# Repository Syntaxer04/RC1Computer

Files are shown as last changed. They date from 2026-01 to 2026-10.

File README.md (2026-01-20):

# RC1Computer
8-Bit Relay Computer inspired by Harry Porter and DipDot
# General Information
This Computer, inspired Harry H Porter III, Ph.D, Paul Law, and Youtuber DipDot, is (almost) completly made out of relays, 607 of them to be exact.

# Specifications
- 32 kb RAM
- It has ~11~ 15 8 Bit Registers. Some of them can also funtcion as 16 Bit Registers.
- A clock rate Between 3 and 8 Hertz
- 8 Bit Data and Instruction Bus, as well as an 16* Bit Adress Bus
<sub>*only 15 bits are actually used, but the 16th Bit is still usable for other Peripherals/More Memeory</sub>

# Changes in V0.2
- Changed how I managed the Bus on the RC-1. The Bus Board now encompasses all Register Signals and otherwise, except for the Timing pulses, which is only used by the Controller.
- Caught most the Routing mistakes I made in the first Version. The second run really helped spotting obvious and not so obvious mistakes.
- Added a board for the front panel functions. The switches are not mounted on the Board however, and so are the LEDs.
- I also started experimenting with Capacitor Storage. I included my initial design in this version.
- The memory board had an overhaul, with more isolation and better logic.
- The ALU has been split into two boards. I was able to do this because of the new backplane.

# Future features
- ~I want to make some sort Storage medium. A Tape interface, similar to DipDot's design, would be nice, although for a computer like that kind of lame in my opinion. I am thinking more like a paper based interface, like the one Usagi electric build for the [UE1](https://www.youtube.com/playlist?list=PLnw98JPyObn0v-98gRV9PfzAQONTKxql3). One Slight Problem thogh: _Reading_ may be somewhat easy, the _writing_ on the other hand may be a little challenge... We'll burn that bridge when we get there.~
- Tape Loader has been added, function not Tested however.
- The Second thing i want to make for this project is some sort of Serial/ Terminal output. That itself is not that hard all things considered, it's nearly a chip solution. The real problem is that the Computer most likely lacks any sort of speed for that kind of outpu. So i either have to buffer the output, make it _exceptionaly_ slow, or find some other way of sending a serial signal of of the Computer.

# Links
[Paul Law´s Youtube channel](https://www.youtube.com/@paul80nd), and his [personal Blog](https://www.relaycomputer.co.uk/).
[Harry Porter´s Webiste](https://web.cecs.pdx.edu/~harry/Relay/index.html), specifically, [this PDF](https://web.cecs.pdx.edu/~harry/Relay/RelayPaper.pdf).
Lastly, [DipDot´s Youtube channel](https://www.youtube.com/@dipdoting). He was the main inspiration for this project and his videos are well made.

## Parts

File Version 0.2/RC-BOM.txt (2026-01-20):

Bill of Materials

ALU-LOGIC: 	 52 1N914  
	  	 45 LEDs
		 52 HK19F-DC5V Relays
		 45 330 Ohm Resistors

ALU-FULLADDER:	 62 1N914  
	  	 21 LEDs
		 63 HK19F-DC5V Relays
		 21 330 Ohm Resistors

CONTROLLER:	 60 1N914  
	  	 2 2*12 connector
		 60 HK19F-DC5V Relays

DECODER:	 73 1N914  
	  	 2 2*13 connector
		 66 HK19F-DC5V Relays

INCREMENTER:	 66 1N914  
	  	 18 LEDs
		 66 HK19F-DC5V Relays
		 18 330 Ohm Resistors

MEMORY:		 2 1uF Capacitors
		 23 1N914  
		 21 HK19F-DC5V Relays
		 1 CY62256-70PC 256k RAM
		 1 ULN2803A

TIMING:		 4 10k uF Capacitors
		 68 1N914  
		 2 2*12 connector
		 68 HK19F-DC5V Relays

REGISTER:	 39 1N914 
		 23 LEDs
		 23 330 Ohm Resistors
		 39 HK19F-DC5V Relays
		 1 2*12 connector
		 1 2*13 connector

FRONT PANEL:	 76 LEDs 
		 76 330 Ohm Resitors
		 67 SPST Switches (~50/50 of momentary and non-momentary switches)
		 
( P.S: You need the register board 5 times for all the registers not included on any other board )

In total:
Relays: 591
Diodes: 599
LEDs: 275 (I have chosen 8mm LEDs for the Front Panel and 3mm LEDs for everything else, but 5mm LEDs fir on all boards)
RESISTORS: 275
CAPACITORS: 7 (The filter capacitor may not be needed on the Bridge board and the 4 capacitors on the Timing board may be too low of a value, and thus the oscillator may (or at least try to) run too fast for the relays)
CONNECTORS: 5 2*12 connector
	    3 2*13 connector
	    4 2*2 connector
	    4 2*32 idc connector
	    12 2*50 edge card connector

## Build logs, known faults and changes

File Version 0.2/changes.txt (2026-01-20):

Changes for Version 0.2:

	- fixed (hopefully) most of the wiring mistakes that I made
	- changed the 3-to-8 Decoder configuration so that 000 is the NOP instruction
	- changed the Bridge board and the connectors I use for the Boards
 	- Added a few boards to the System ( Storage, interfacing, etc.)

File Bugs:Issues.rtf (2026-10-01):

BUGS/ISSUES:
• Every jump/goto executes the last half of the dress a a command
⁃ This is because the jump command doesn’t skip the MSB of the jump address, making the computer see it as a command. Currently no successful workaround, trying a few ideas though
• Commands mislabeled
⁃ Some commands I have added to my computer are currently mislabeled or not functioning like it was described in the documentation. Since there aren’t that many commands to try, and if one alternative works you can extrapolate the rest, its relatively easy to correct all commands
⁃ There are some commands I still need to add though. For instance, the 16 Bit variety of inc and move are not implemented and some new commands are also not finished, such as HALT or the IN command.
• Bus weirdness >:(
⁃ The buses of my system are somewhat wonky and make, at times, zero sense. For example, the increment function of the ALU gave back results with the MSB and LSB swapped, so that 00000001 became 10000000. This is very not good.
⁃ The somewhat standard components I used for this computer are somewhat cool, the problem arises when you to change one single thing, and now the whole system just doesn’t work anymore. I have two solutions for this problem:
⁃ The first option would be to make the separate components less standard. The issue with that would be that if you have an issue with the system, it would be less straightforward to troubleshoot the system.
⁃ The second, and my preferred option, would be to make bigger compartments, where, for example, all registers would have one block, the ALU would have one block and the other operational logic would have one block. This could also make it harder to troubleshoot, but could make the design also a bit more modular, since you could just add more logic if you need to. Without making the system more cluttered.
• Simplification
⁃ The next thing to do after most of the bugs and weirdness is found, is to simplify the design and reduce the chip count in general. We are currently sitting at a cool ~430 separate chips. This is a really big amount of chips, way more than I anticipated. Not only would this make me go broke at the moment, but it would most likely use a LOT of power, let’s quickly do some napkin math:
⁃ Buffers tend to use around 240 to 300 mW each
⁃ Quad-Gate chips such as a 74LS00 use around 9 to 22 mW
⁃ Since I want to use a SRAM chip so I don’t have to build a refresh circuit, it would consume around 200 to 400 mW
⁃ We have 132 Buffers, 250 Gates, and a few miscellaneous chips such as counters
⁃ If we were to assume the worst possible situation, we would have a consumption of… around 45 W of power!
⁃ Since this computer primarily runs on 5 Volts, this would equate to an amperage of 9 amps.
⁃ This is of course the worst possible outcome of all chips having 100% utility, which is highly unlikely. The consumption will probably not even be half of the worst case. The only thing I could see becoming an issue would be the heat produced by so many chips.
⁃

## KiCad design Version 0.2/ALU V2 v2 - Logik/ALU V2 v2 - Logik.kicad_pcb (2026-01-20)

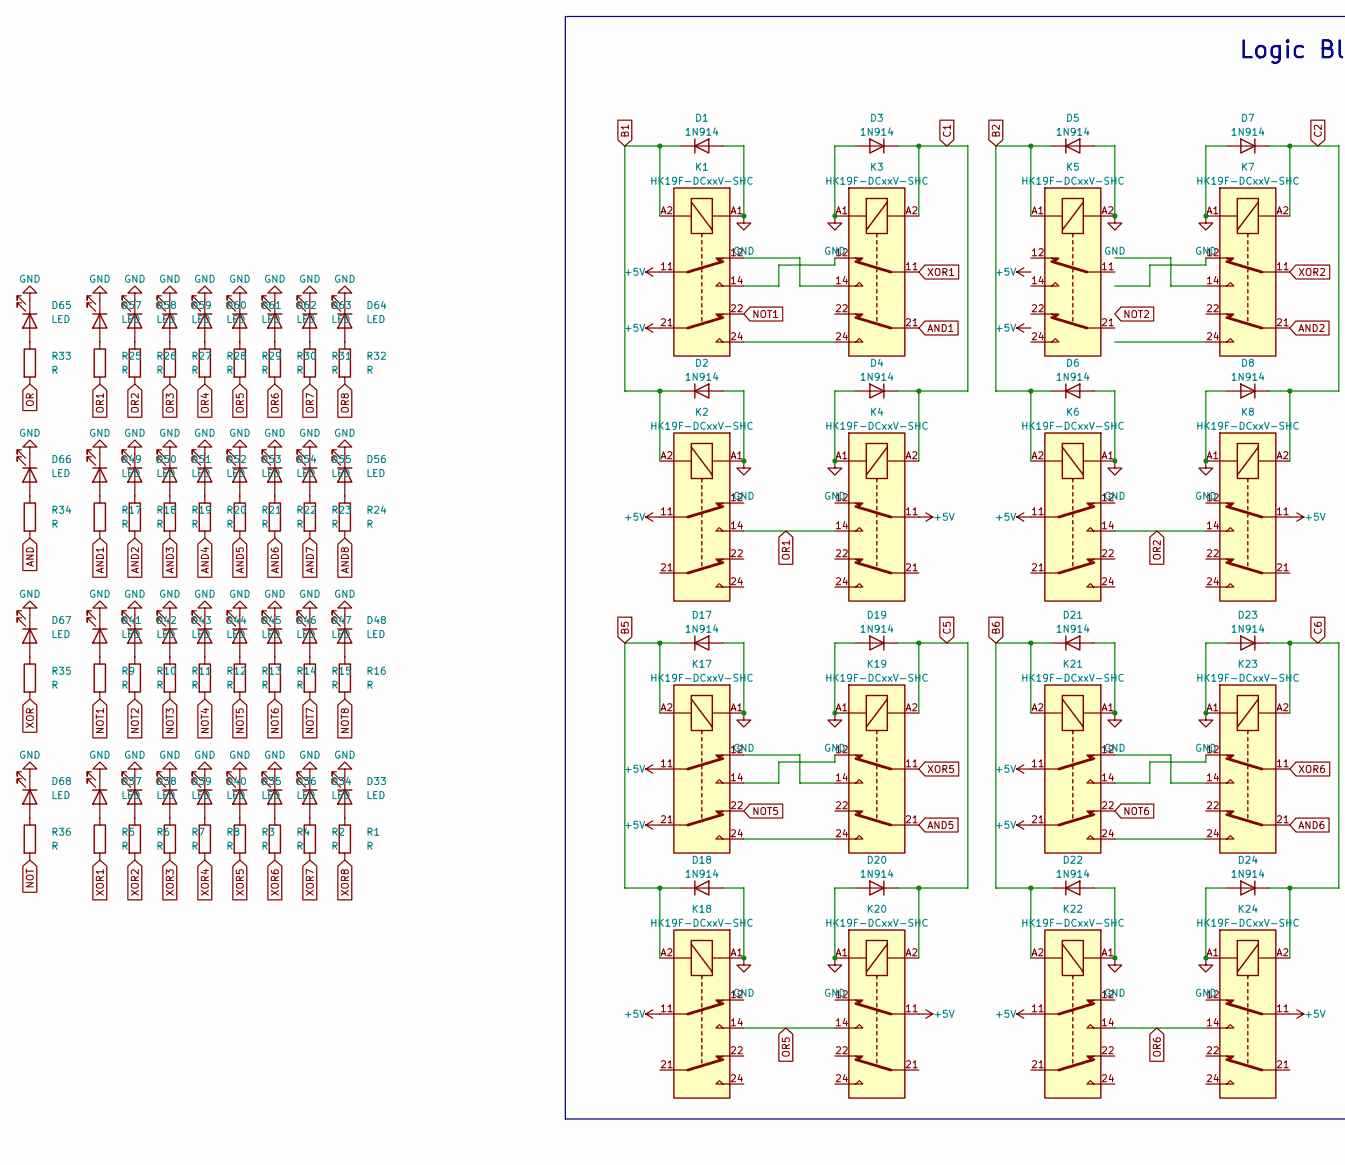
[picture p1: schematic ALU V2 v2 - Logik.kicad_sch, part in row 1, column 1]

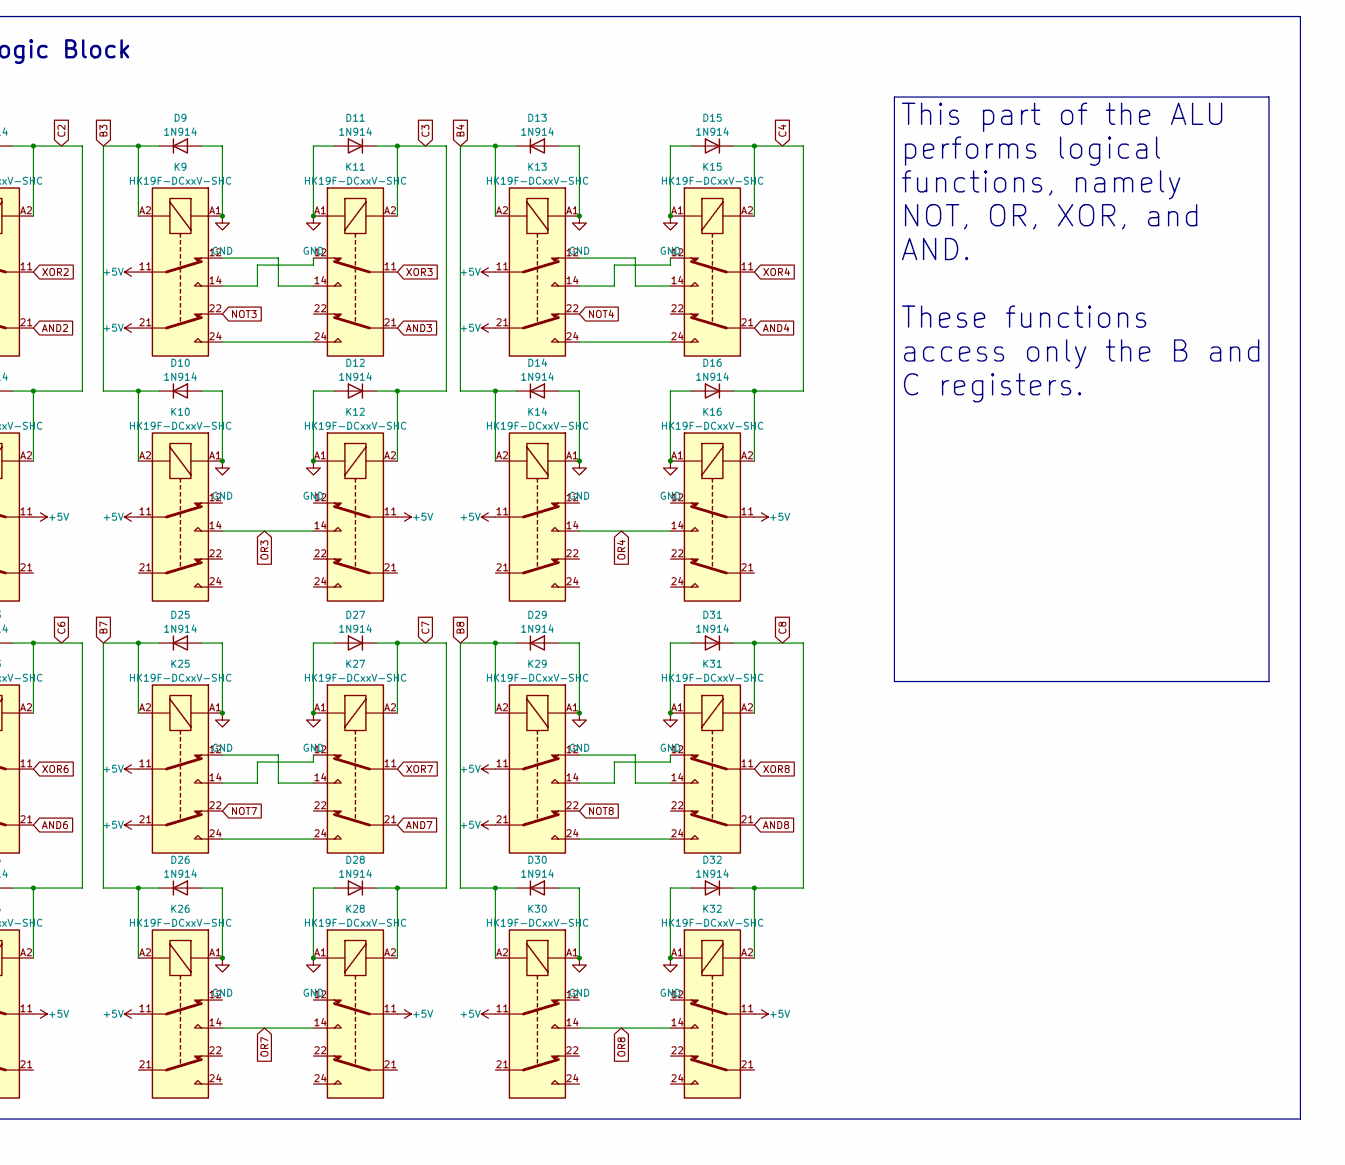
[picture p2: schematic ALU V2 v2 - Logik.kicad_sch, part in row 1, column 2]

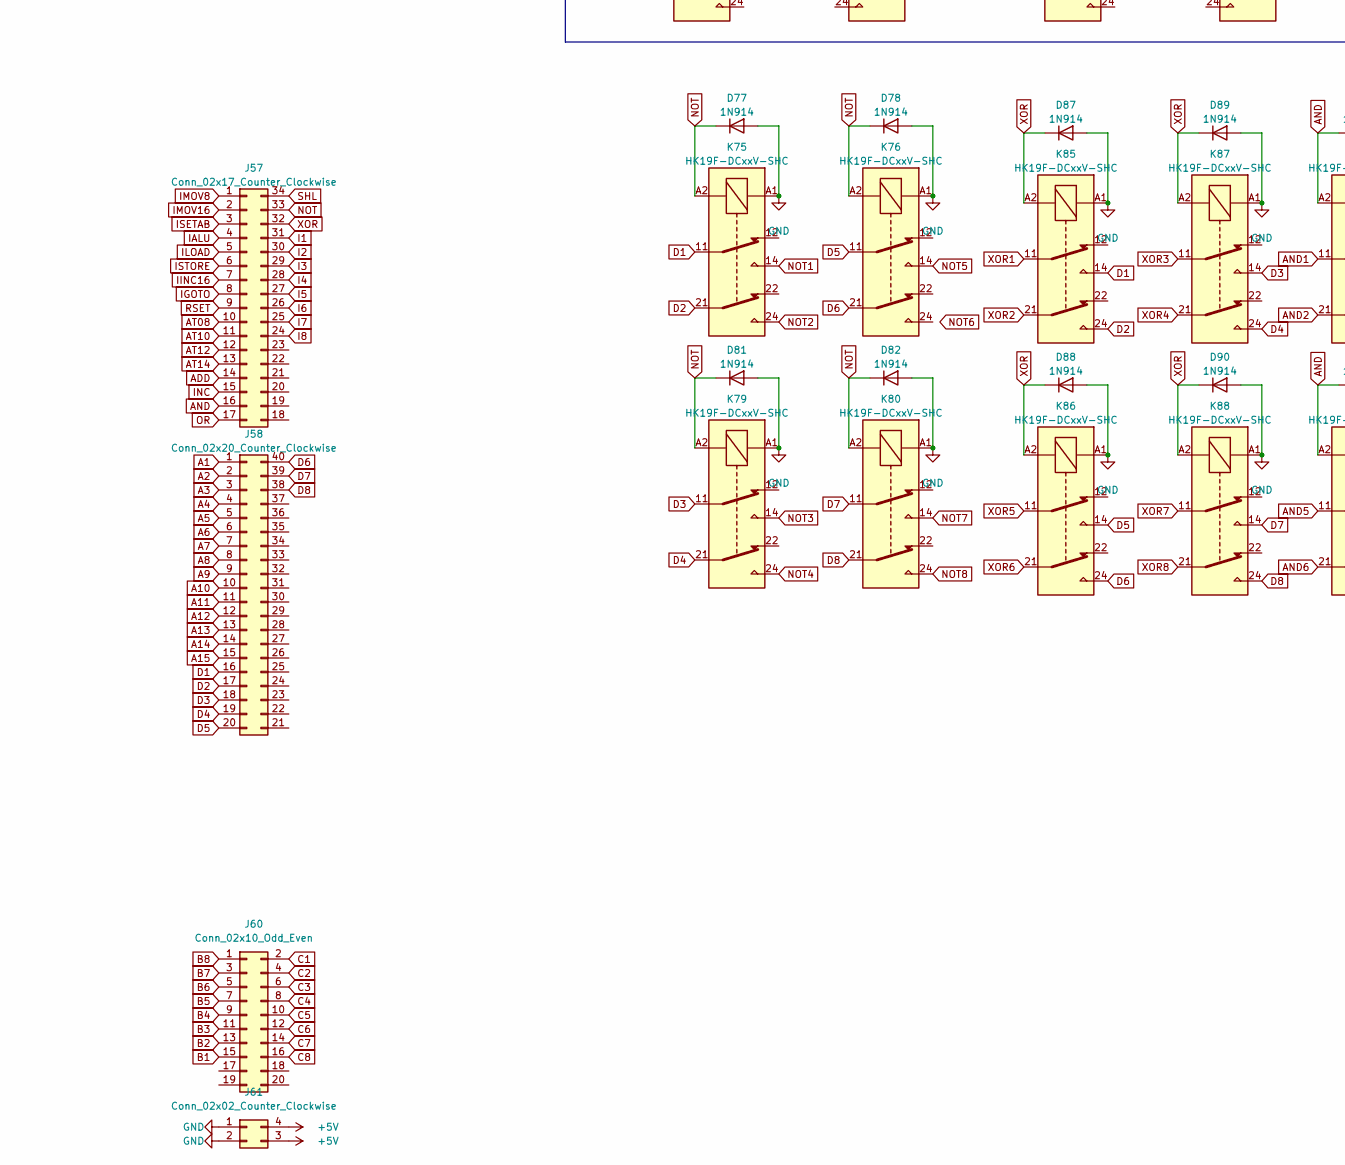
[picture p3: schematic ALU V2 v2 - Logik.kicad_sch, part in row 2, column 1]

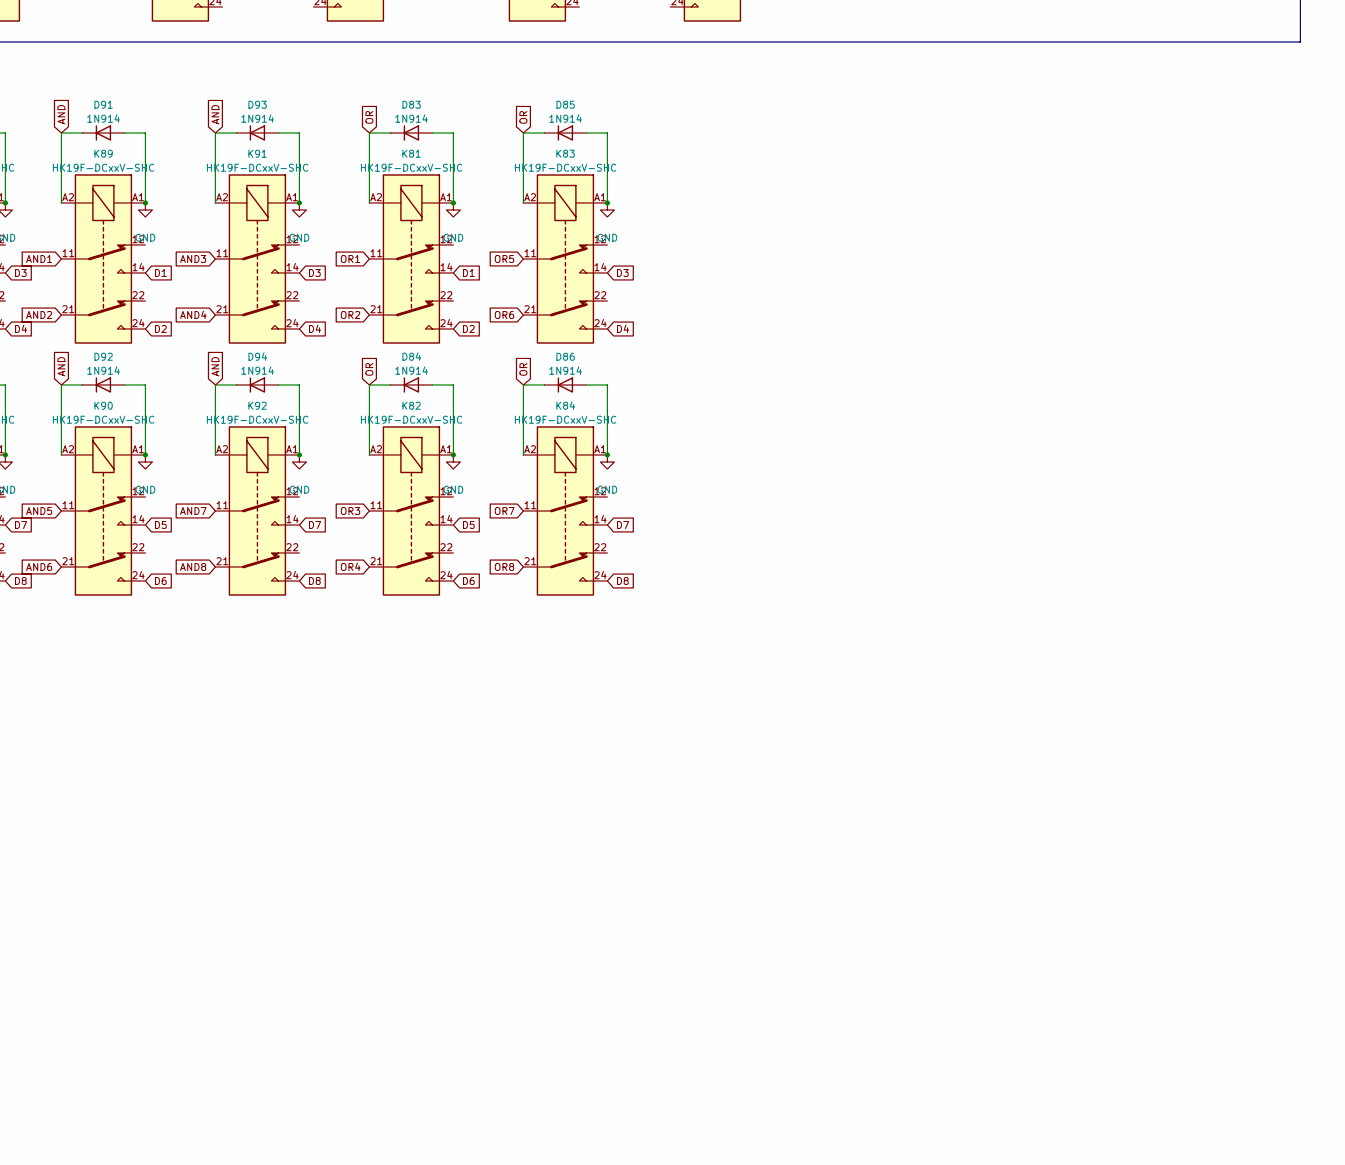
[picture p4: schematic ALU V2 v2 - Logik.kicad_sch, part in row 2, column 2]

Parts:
D1, D2, D3, D4, D5, D6, D7, D8, D9, D10, D11, D12, D13, D14, D15, D16, D17, D18, D19, D20, D21, D22, D23, D24, D25, D26, D27, D28, D29, D30, D31, D32, D77, D78, D81, D82, D83, D84, D85, D86, D87, D88, D89, D90, D91, D92, D93, D94: 1N914; D_DO-35_SOD27_P7.62mm_Horizontal
D33, D34, D35, D36, D37, D38, D39, D40, D41, D42, D43, D44, D45, D46, D47, D48, D49, D50, D51, D52, D53, D54, D55, D56, D57, D58, D59, D60, D61, D62, D63, D64, D65, D66, D67, D68: LED; LED_D5.0mm
J57: Conn_02x17_Counter_Clockwise; PinSocket_2x17_P2.54mm_Horizontal
J58: Conn_02x20_Counter_Clockwise; PinSocket_2x20_P2.54mm_Horizontal
J60: Conn_02x10_Odd_Even; PinSocket_2x10_P2.54mm_Horizontal
J61: Conn_02x02_Counter_Clockwise; PinSocket_2x02_P2.54mm_Horizontal
K1, K2, K3, K4, K5, K6, K7, K8, K9, K10, K11, K12, K13, K14, K15, K16, K17, K18, K19, K20, K21, K22, K23, K24, K25, K26, K27, K28, K29, K30, K31, K32, K75, K76, K79, K80, K81, K82, K83, K84, K85, K86, K87, K88, K89, K90, K91, K92: HK19F-DCxxV-SHC; Relay_DPDT_Finder_30.22
R1, R2, R3, R4, R5, R6, R7, R8, R9, R10, R11, R12, R13, R14, R15, R16, R17, R18, R19, R20, R21, R22, R23, R24, R25, R26, R27, R28, R29, R30, R31, R32, R33, R34, R35, R36: R; R_Axial_DIN0309_L9.0mm_D3.2mm_P12.70mm_Horizontal

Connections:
+5V: J61.3, J61.4, K1.11, K1.21, K2.11, K4.11, K5.11, K5.21, K6.11, K8.11, K9.11, K9.21, K10.11, K12.11, K13.11, K13.21, K14.11, K16.11, K17.11, K17.21, K18.11, K20.11, K21.11, K21.21, K22.11, K24.11, K25.11, K25.21, K26.11, K28.11, K29.11, K29.21, K30.11, K32.11
A1: J58.1
A2: J58.2
A3: J58.3
A4: J58.4
A5: J58.5
A6: J58.6
A7: J58.7
A8: J58.8
A9: J58.9
A10: J58.10
A11: J58.11
A12: J58.12
A13: J58.13
A14: J58.14
A15: J58.15
ADD: J57.14
AND: D91.1 (K), D92.1 (K), D93.1 (K), D94.1 (K), J57.16, K89.A2, K90.A2, K91.A2, K92.A2, R34.2
AND1: K3.21, K89.11, R17.2
AND2: K7.21, K89.21, R18.2
AND3: K11.21, K91.11, R19.2
AND4: K15.21, K91.21, R20.2
AND5: K19.21, K90.11, R21.2
AND6: K23.21, K90.21, R22.2
AND7: K27.21, K92.11, R23.2
AND8: K31.21, K92.21, R24.2
AT08: J57.10
AT10: J57.11
AT12: J57.12
AT14: J57.13
B1: D1.1 (K), D2.1 (K), J60.15, K1.A2, K2.A2
B3: D9.1 (K), D10.1 (K), J60.11, K9.A2, K10.A2
B4: D13.1 (K), D14.1 (K), J60.9, K13.A2, K14.A2
B5: D17.1 (K), D18.1 (K), J60.7, K17.A2, K18.A2
B6: D21.1 (K), D22.1 (K), J60.5, K21.A2, K22.A2
B7: D25.1 (K), D26.1 (K), J60.3, K25.A2, K26.A2
B8: D29.1 (K), D30.1 (K), J60.1, K29.A2, K30.A2
C1: D3.1 (K), D4.1 (K), J60.2, K3.A2, K4.A2
C2: D7.1 (K), D8.1 (K), J60.4, K7.A2, K8.A2
C3: D11.1 (K), D12.1 (K), J60.6, K11.A2, K12.A2
C4: D15.1 (K), D16.1 (K), J60.8, K15.A2, K16.A2
C5: D19.1 (K), D20.1 (K), J60.10, K19.A2, K20.A2
C6: D23.1 (K), D24.1 (K), J60.12, K23.A2, K24.A2
C7: D27.1 (K), D28.1 (K), J60.14, K27.A2, K28.A2
C8: D31.1 (K), D32.1 (K), J60.16, K31.A2, K32.A2
D1: J58.16, K75.11, K81.14, K85.14, K89.14
D2: J58.17, K75.21, K81.24, K85.24, K89.24
D3: J58.18, K79.11, K83.14, K87.14, K91.14
D4: J58.19, K79.21, K83.24, K87.24, K91.24
D5: J58.20, K76.11, K82.14, K86.14, K90.14
D6: J58.40, K76.21, K82.24, K86.24, K90.24
D7: J58.39, K80.11, K84.14, K88.14, K92.14
D8: J58.38, K80.21, K84.24, K88.24, K92.24
I1: J57.31
I2: J57.30
I3: J57.29
I4: J57.28
I5: J57.27
I6: J57.26
I7: J57.25
I8: J57.24
IALU: J57.4
IGOTO: J57.8
IINC16: J57.7
ILOAD: J57.5
IMOV8: J57.1
IMOV16: J57.2
INC: J57.15
ISETAB: J57.3
ISTORE: J57.6
NOT: D77.1 (K), D78.1 (K), D81.1 (K), D82.1 (K), J57.33, K75.A2, K76.A2, K79.A2, K80.A2, R36.2
NOT1: K1.22, K75.14, R9.2
NOT2: K5.22, K75.24, R10.2
NOT3: K9.22, K79.14, R11.2
NOT4: K13.22, K79.24, R12.2
NOT5: K17.22, K76.14, R13.2
NOT6: K21.22, R14.2
NOT7: K25.22, K80.14, R15.2
NOT8: K29.22, K80.24, R16.2
unnamed: D33.2 (A), R1.1
unnamed: D34.2 (A), R2.1
unnamed: D35.2 (A), R3.1
unnamed: D36.2 (A), R4.1
unnamed: D37.2 (A), R5.1
unnamed: D38.2 (A), R6.1
unnamed: D39.2 (A), R7.1
unnamed: D40.2 (A), R8.1
unnamed: D41.2 (A), R9.1
unnamed: D42.2 (A), R10.1
unnamed: D43.2 (A), R11.1
unnamed: D44.2 (A), R12.1
unnamed: D45.2 (A), R13.1
unnamed: D46.2 (A), R14.1
unnamed: D47.2 (A), R15.1
unnamed: D48.2 (A), R16.1
unnamed: D49.2 (A), R17.1
unnamed: D50.2 (A), R18.1
unnamed: D51.2 (A), R19.1
unnamed: D52.2 (A), R20.1
unnamed: D53.2 (A), R21.1
unnamed: D54.2 (A), R22.1
unnamed: D55.2 (A), R23.1
unnamed: D56.2 (A), R24.1
unnamed: D57.2 (A), R25.1
unnamed: D58.2 (A), R26.1
unnamed: D59.2 (A), R27.1
unnamed: D60.2 (A), R28.1
unnamed: D61.2 (A), R29.1
unnamed: D62.2 (A), R30.1
unnamed: D63.2 (A), R31.1
unnamed: D64.2 (A), R32.1
unnamed: D65.2 (A), R33.1
unnamed: D66.2 (A), R34.1
unnamed: D67.2 (A), R35.1
unnamed: D68.2 (A), R36.1
unnamed: K1.12, K3.14
unnamed: K1.14, K3.12
unnamed: K1.24, K3.24
unnamed: K5.12, K7.14
unnamed: K5.14, K7.12
unnamed: K5.24, K7.24
unnamed: K9.14, K11.12
unnamed: K9.12, K11.14
unnamed: K9.24, K11.24
unnamed: K13.12, K15.14
unnamed: K13.14, K15.12
unnamed: K13.24, K15.24
unnamed: K17.12, K19.14
unnamed: K17.14, K19.12
unnamed: K17.24, K19.24
unnamed: K21.12, K23.14
unnamed: K21.14, K23.12
unnamed: K21.24, K23.24
unnamed: K25.12, K27.14
unnamed: K25.14, K27.12
unnamed: K25.24, K27.24
unnamed: K29.12, K31.14
unnamed: K29.14, K31.12
unnamed: K29.24, K31.24
OR: D83.1 (K), D84.1 (K), D85.1 (K), D86.1 (K), J57.17, K81.A2, K82.A2, K83.A2, K84.A2, R33.2
OR1: K2.14, K4.14, K81.11, R25.2
OR2: K6.14, K8.14, K81.21, R26.2
OR3: K10.14, K12.14, K82.11, R27.2
OR4: K14.14, K16.14, K82.21, R28.2
OR5: K18.14, K20.14, K83.11, R29.2
OR6: K22.14, K24.14, K83.21, R30.2
OR7: K26.14, K28.14, K84.11, R31.2
OR8: K30.14, K32.14, K84.21, R32.2
RSET: J57.9
SHL: J57.34
XOR: D87.1 (K), D88.1 (K), D89.1 (K), D90.1 (K), J57.32, K85.A2, K86.A2, K87.A2, K88.A2, R35.2
XOR1: K3.11, K85.11, R5.2
XOR2: K7.11, K85.21, R6.2
XOR3: K11.11, K87.11, R7.2
XOR4: K15.11, K87.21, R8.2
XOR5: K19.11, K86.11, R3.2
XOR6: K23.11, K86.21, R4.2
XOR7: K27.11, K88.11, R2.2
XOR8: K31.11, K88.21, R1.2

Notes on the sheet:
Logic Block
This part of the ALU performs logical functions, namely NOT, OR, XOR, and AND. These functions access only the B and C registers.

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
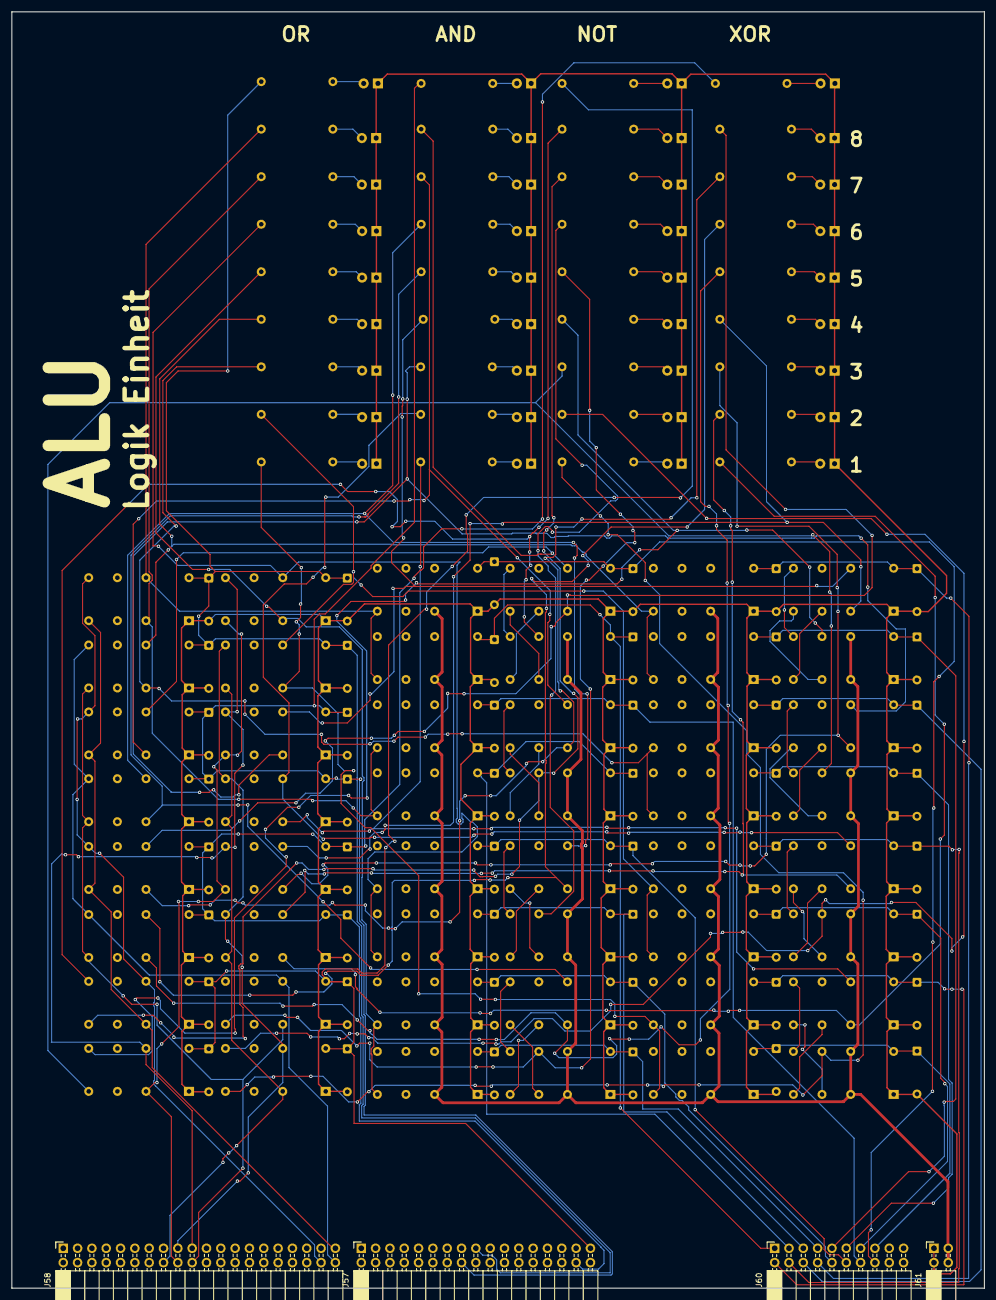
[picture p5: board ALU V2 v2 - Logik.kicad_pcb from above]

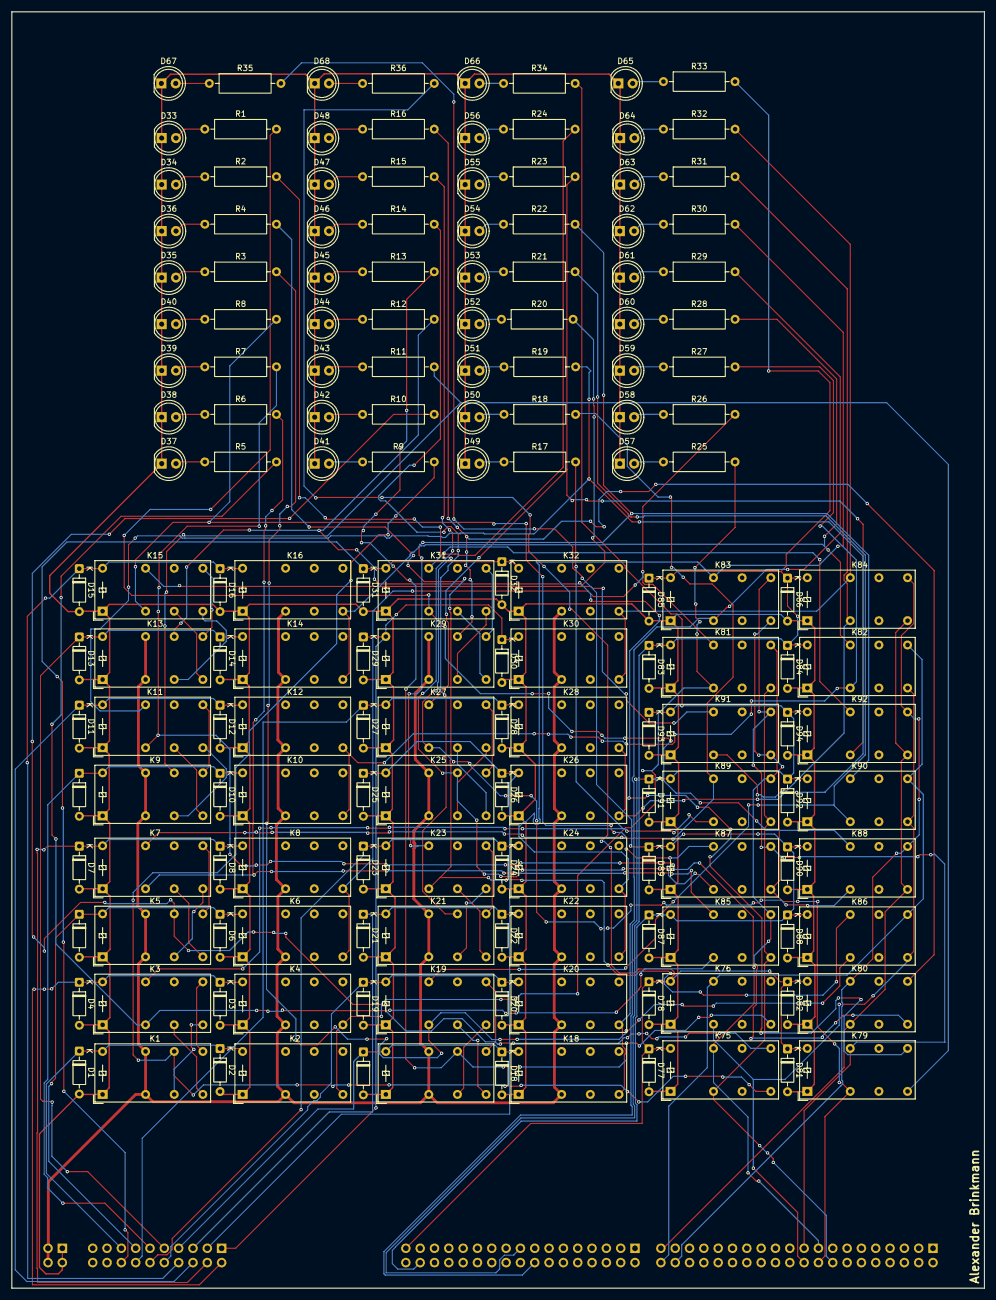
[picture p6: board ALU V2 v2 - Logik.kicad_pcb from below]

Board: 2 copper layers, 172.5 x 226.3 mm, 172 parts (168 on the bottom side), 122 nets.

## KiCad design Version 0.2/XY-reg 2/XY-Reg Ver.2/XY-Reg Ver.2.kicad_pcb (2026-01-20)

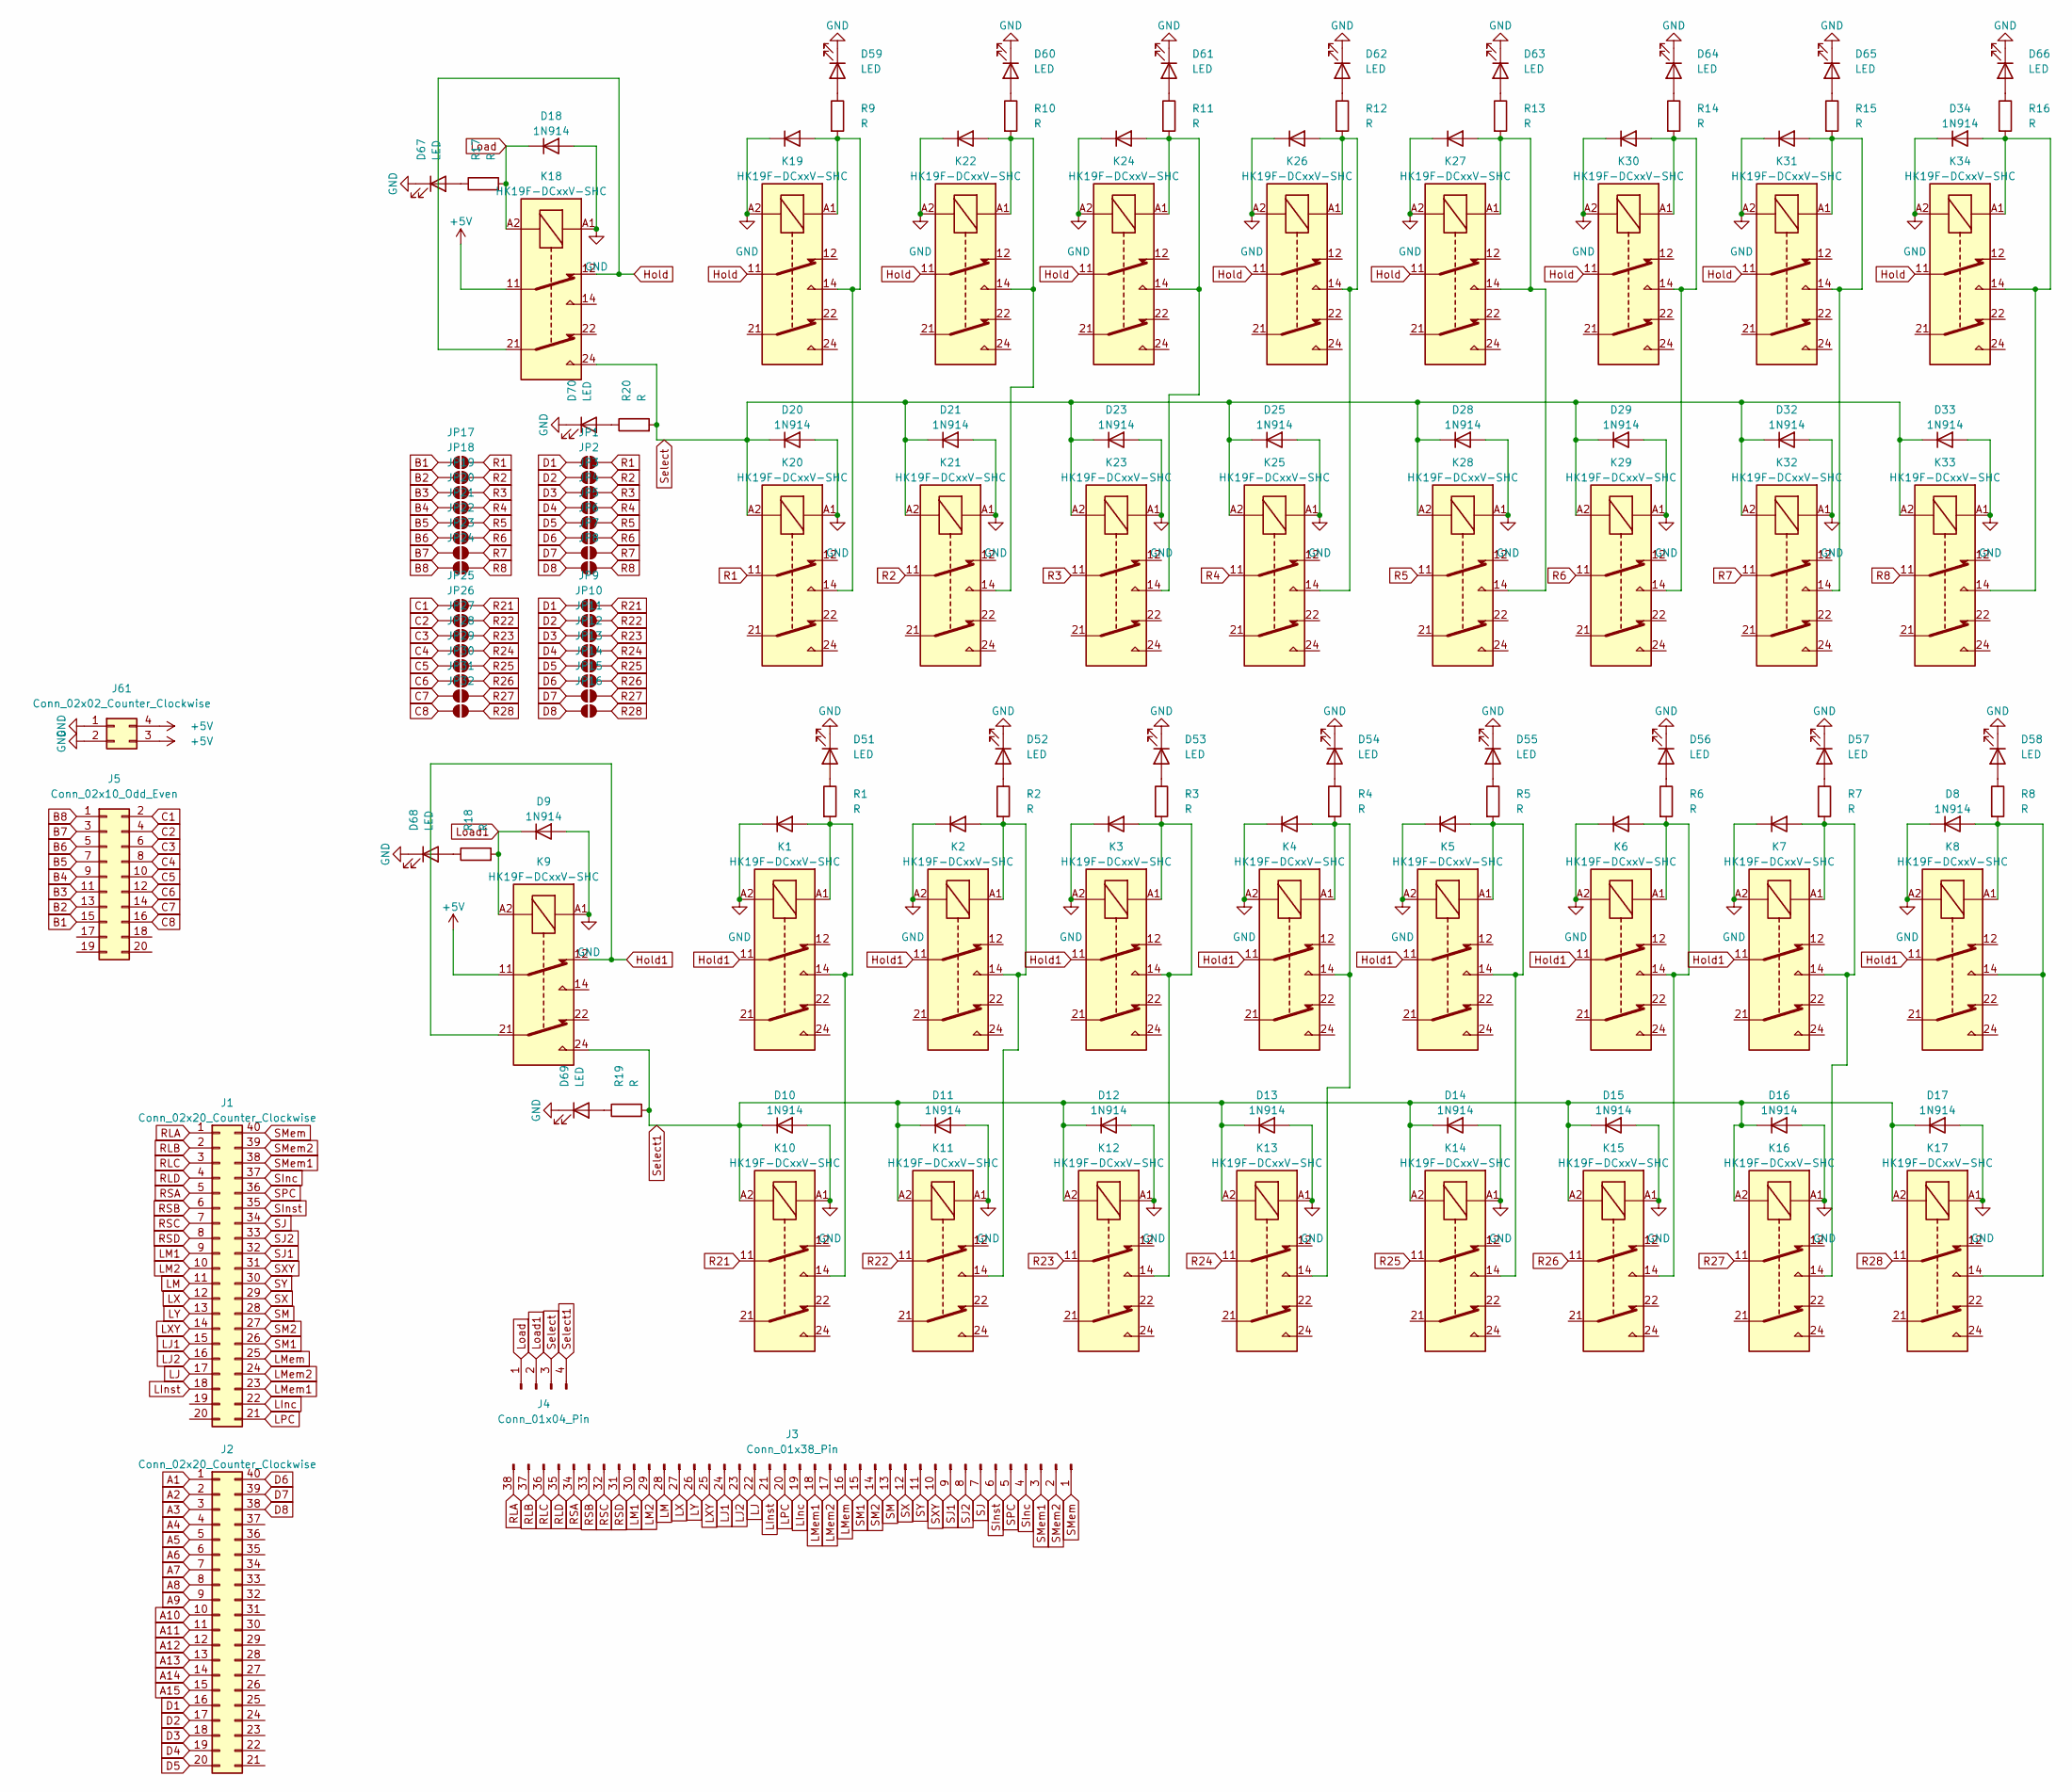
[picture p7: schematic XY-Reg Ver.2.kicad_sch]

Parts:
D1, D2, D3, D4, D5, D6, D7, D8, D9, D10, D11, D12, D13, D14, D15, D16, D17, D18, D19, D20, D21, D22, D23, D24, D25, D26, D27, D28, D29, D30, D31, D32, D33, D34: 1N914; D_DO-35_SOD27_P7.62mm_Horizontal
D51, D52, D53, D54, D55, D56, D57, D58, D59, D60, D61, D62, D63, D64, D65, D66, D67, D68, D70: LED; LED_D5.0mm ohne SilkS
D69: LED; LED_D5.0mm
J1, J2: Conn_02x20_Counter_Clockwise; PinSocket_2x20_P2.54mm_Horizontal
J3: Conn_01x38_Pin; PinHeader_1x38_P2.54mm_Vertical
J4: Conn_01x04_Pin; PinHeader_1x04_P2.54mm_Vertical
J5: Conn_02x10_Odd_Even; PinHeader_2x10_P2.54mm_Horizontal
J61: Conn_02x02_Counter_Clockwise; PinSocket_2x02_P2.54mm_Vertical
JP1, JP2, JP3, JP4, JP5, JP6, JP7, JP8, JP9, JP10, JP11, JP12, JP13, JP14, JP15, JP16, JP17, JP18, JP19, JP20, JP21, JP22, JP23, JP24, JP25, JP26, JP27, JP28, JP29, JP30, JP31, JP32: SolderJumper_2_Open; SolderJumper-2_P1.3mm_Open_Pad1.0x1.5mm
K1, K2, K3, K4, K5, K6, K7, K8, K9, K10, K11, K12, K13, K14, K15, K16, K17, K18, K19, K20, K21, K22, K23, K24, K25, K26, K27, K28, K29, K30, K31, K32, K33, K34: HK19F-DCxxV-SHC; Relay_DPDT_Finder_30.22 ohne SilkS
R1, R2, R3, R4, R5, R6, R7, R8, R9, R10, R11, R12, R13, R14, R15, R16, R17, R18, R19, R20: R; R_Axial_DIN0204_L3.6mm_D1.6mm_P7.62mm_Horizontal

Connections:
+5V: J61.3, J61.4, K9.11, K18.11
A1: J2.1
A2: J2.2
A3: J2.3
A4: J2.4
A5: J2.5
A6: J2.6
A7: J2.7
A8: J2.8
A9: J2.9
A10: J2.10
A11: J2.11
A12: J2.12
A13: J2.13
A14: J2.14
A15: J2.15
B1: J5.15, JP17.1 (A)
B2: J5.13, JP18.1 (A)
B3: J5.11, JP19.1 (A)
B4: J5.9, JP20.1 (A)
B5: J5.7, JP21.1 (A)
B6: J5.5, JP22.1 (A)
B7: J5.3, JP23.1 (A)
B8: J5.1, JP24.1 (A)
C1: J5.2, JP25.1 (A)
C2: J5.4, JP26.1 (A)
C3: J5.6, JP27.1 (A)
C4: J5.8, JP28.1 (A)
C5: J5.10, JP29.1 (A)
C6: J5.12, JP30.1 (A)
C7: J5.14, JP31.1 (A)
C8: J5.16, JP32.1 (A)
D1: J2.16, JP1.1 (A), JP9.1 (A)
D2: J2.17, JP2.1 (A), JP10.1 (A)
D3: J2.18, JP3.1 (A), JP11.1 (A)
D4: J2.19, JP4.1 (A), JP12.1 (A)
D5: J2.20, JP5.1 (A), JP13.1 (A)
D6: J2.40, JP6.1 (A), JP14.1 (A)
D7: J2.39, JP7.1 (A), JP15.1 (A)
D8: J2.38, JP8.1 (A), JP16.1 (A)
GND: D1.1 (K), D2.1 (K), D3.1 (K), D4.1 (K), D5.1 (K), D6.1 (K), D7.1 (K), D8.1 (K), D9.2 (A), D10.2 (A), D11.2 (A), D12.2 (A), D13.2 (A), D14.2 (A), D15.2 (A), D16.2 (A), D17.2 (A), D18.2 (A), D19.1 (K), D20.2 (A), D21.2 (A), D22.1 (K), D23.2 (A), D24.1 (K), D25.2 (A), D26.1 (K), D27.1 (K), D28.2 (A), D29.2 (A), D30.1 (K), D31.1 (K), D32.2 (A), D33.2 (A), D34.1 (K), D51.1 (K), D52.1 (K), D53.1 (K), D54.1 (K), D55.1 (K), D56.1 (K), D57.1 (K), D58.1 (K), D59.1 (K), D60.1 (K), D61.1 (K), D62.1 (K), D63.1 (K), D64.1 (K), D65.1 (K), D66.1 (K), D67.1 (K), D68.1 (K), D69.1 (K), D70.1 (K), J61.1, J61.2, K1.A2, K2.A2, K3.A2, K4.A2, K5.A2, K6.A2, K7.A2, K8.A2, K9.A1, K10.A1, K11.A1, K12.A1, K13.A1, K14.A1, K15.A1, K16.A1, K17.A1, K18.A1, K19.A2, K20.A1, K21.A1, K22.A2, K23.A1, K24.A2, K25.A1, K26.A2, K27.A2, K28.A1, K29.A1, K30.A2, K31.A2, K32.A1, K33.A1, K34.A2
Hold: K18.12, K18.21, K19.11, K22.11, K24.11, K26.11, K27.11, K30.11, K31.11, K34.11
Hold1: K1.11, K2.11, K3.11, K4.11, K5.11, K6.11, K7.11, K8.11, K9.12, K9.21
LInc: J1.22, J3.19
LInst: J1.18, J3.21
LJ1: J1.15, J3.24
LJ2: J1.16, J3.23
LJ: J1.17, J3.22
LM: J1.11, J3.28
LM1: J1.9, J3.30
LM2: J1.10, J3.29
LMem: J1.25, J3.16
LMem1: J1.23, J3.18
LMem2: J1.24, J3.17
LPC: J1.21, J3.20
LX: J1.12, J3.27
LXY: J1.14, J3.25
LY: J1.13, J3.26
Load: D18.1 (K), J4.1, K18.A2, R17.2
Load1: D9.1 (K), J4.2, K9.A2, R18.2
unnamed: D1.2 (A), K1.14, K1.A1, K10.14, R1.2
unnamed: D2.2 (A), K2.14, K2.A1, K11.14, R2.2
unnamed: D3.2 (A), K3.14, K3.A1, K12.14, R3.2
unnamed: D4.2 (A), K4.14, K4.A1, K13.14, R4.2
unnamed: D5.2 (A), K5.14, K5.A1, K14.14, R5.2
unnamed: D6.2 (A), K6.14, K6.A1, K15.14, R6.2
unnamed: D7.2 (A), K7.14, K7.A1, K16.14, R7.2
unnamed: D8.2 (A), K8.14, K8.A1, K17.14, R8.2
unnamed: D19.2 (A), K19.14, K19.A1, K20.14, R9.2
unnamed: D22.2 (A), K21.14, K22.14, K22.A1, R10.2
unnamed: D24.2 (A), K23.14, K24.14, K24.A1, R11.2
unnamed: D26.2 (A), K25.14, K26.14, K26.A1, R12.2
unnamed: D27.2 (A), K27.14, K27.A1, K28.14, R13.2
unnamed: D30.2 (A), K29.14, K30.14, K30.A1, R14.2
unnamed: D31.2 (A), K31.14, K31.A1, K32.14, R15.2
unnamed: D34.2 (A), K33.14, K34.14, K34.A1, R16.2
unnamed: D51.2 (A), R1.1
unnamed: D52.2 (A), R2.1
unnamed: D53.2 (A), R3.1
unnamed: D54.2 (A), R4.1
unnamed: D55.2 (A), R5.1
unnamed: D56.2 (A), R6.1
unnamed: D57.2 (A), R7.1
unnamed: D58.2 (A), R8.1
unnamed: D59.2 (A), R9.1
unnamed: D60.2 (A), R10.1
unnamed: D61.2 (A), R11.1
unnamed: D62.2 (A), R12.1
unnamed: D63.2 (A), R13.1
unnamed: D64.2 (A), R14.1
unnamed: D65.2 (A), R15.1
unnamed: D66.2 (A), R16.1
unnamed: D67.2 (A), R17.1
unnamed: D68.2 (A), R18.1
unnamed: D69.2 (A), R19.1
unnamed: D70.2 (A), R20.1
R1: JP1.2 (B), JP17.2 (B), K20.11
R2: JP2.2 (B), JP18.2 (B), K21.11
R3: JP3.2 (B), JP19.2 (B), K23.11
R4: JP4.2 (B), JP20.2 (B), K25.11
R5: JP5.2 (B), JP21.2 (B), K28.11
R6: JP6.2 (B), JP22.2 (B), K29.11
R7: JP7.2 (B), JP23.2 (B), K32.11
R8: JP8.2 (B), JP24.2 (B), K33.11
R21: JP9.2 (B), JP25.2 (B), K10.11
R22: JP10.2 (B), JP26.2 (B), K11.11
R23: JP11.2 (B), JP27.2 (B), K12.11
R24: JP12.2 (B), JP28.2 (B), K13.11
R25: JP13.2 (B), JP29.2 (B), K14.11
R26: JP14.2 (B), JP30.2 (B), K15.11
R27: JP15.2 (B), JP31.2 (B), K16.11
R28: JP16.2 (B), JP32.2 (B), K17.11
RLA: J1.1, J3.38
RLB: J1.2, J3.37
RLC: J1.3, J3.36
RLD: J1.4, J3.35
RSA: J1.5, J3.34
RSB: J1.6, J3.33
RSC: J1.7, J3.32
RSD: J1.8, J3.31
SInc: J1.37, J3.4
SInst: J1.35, J3.6
SJ1: J1.32, J3.9
SJ2: J1.33, J3.8
SJ: J1.34, J3.7
SM: J1.28, J3.13
SM1: J1.26, J3.15
SM2: J1.27, J3.14
SMem: J1.40, J3.1
SMem1: J1.38, J3.3
SMem2: J1.39, J3.2
SPC: J1.36, J3.5
SX: J1.29, J3.12
SXY: J1.31, J3.10
SY: J1.30, J3.11
Select: D20.1 (K), D21.1 (K), D23.1 (K), D25.1 (K), D28.1 (K), D29.1 (K), D32.1 (K), D33.1 (K), J4.3, K18.24, K20.A2, K21.A2, K23.A2, K25.A2, K28.A2, K29.A2, K32.A2, K33.A2, R20.2
Select1: D10.1 (K), D11.1 (K), D12.1 (K), D13.1 (K), D14.1 (K), D15.1 (K), D16.1 (K), D17.1 (K), J4.4, K9.24, K10.A2, K11.A2, K12.A2, K13.A2, K14.A2, K15.A2, K16.A2, K17.A2, R19.2

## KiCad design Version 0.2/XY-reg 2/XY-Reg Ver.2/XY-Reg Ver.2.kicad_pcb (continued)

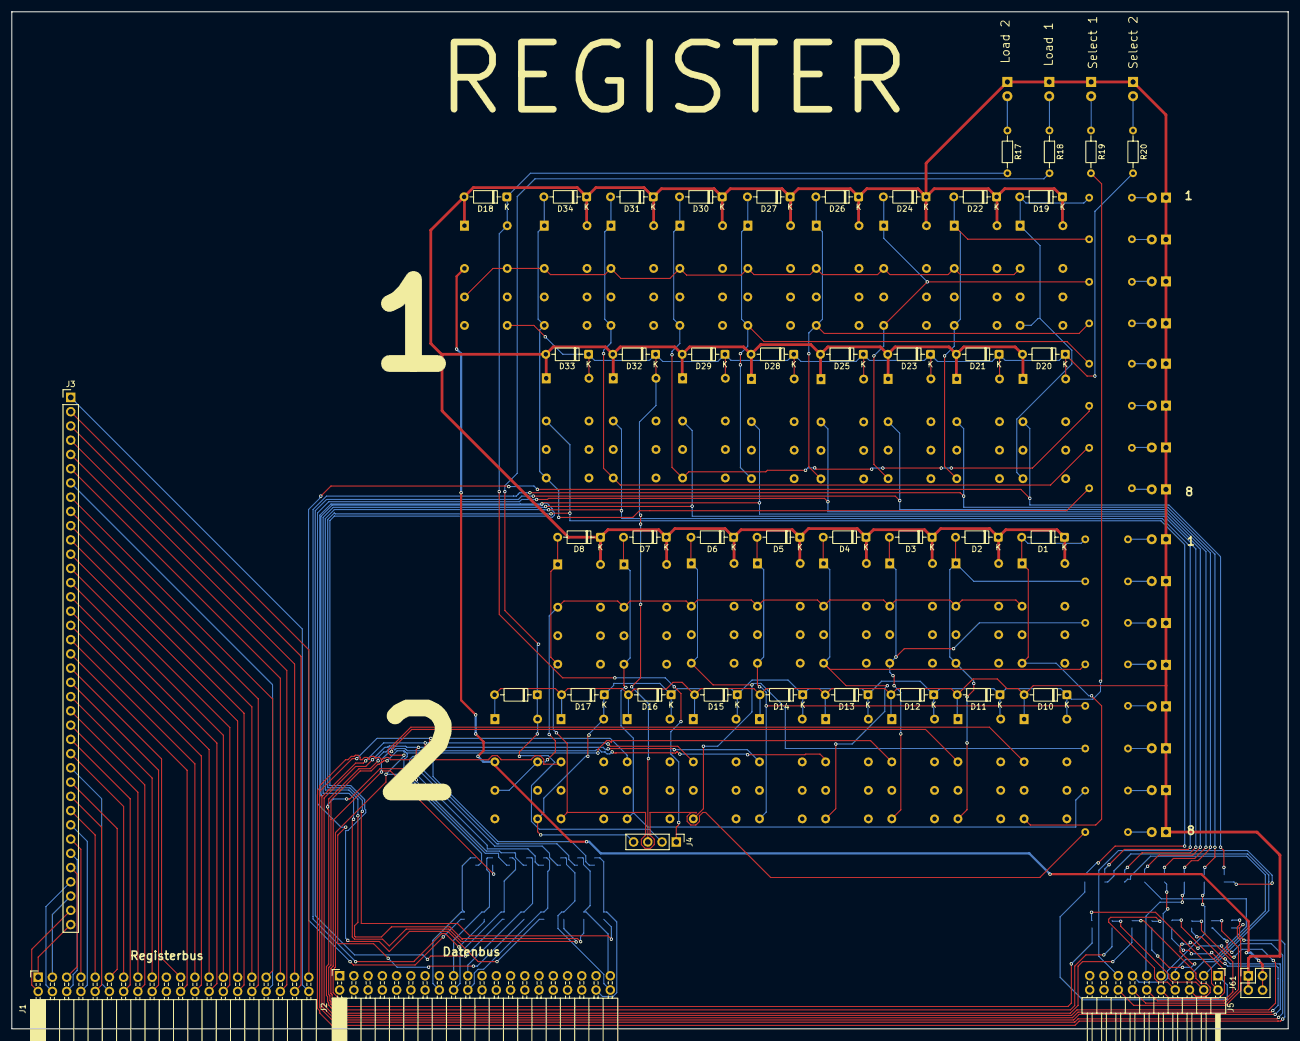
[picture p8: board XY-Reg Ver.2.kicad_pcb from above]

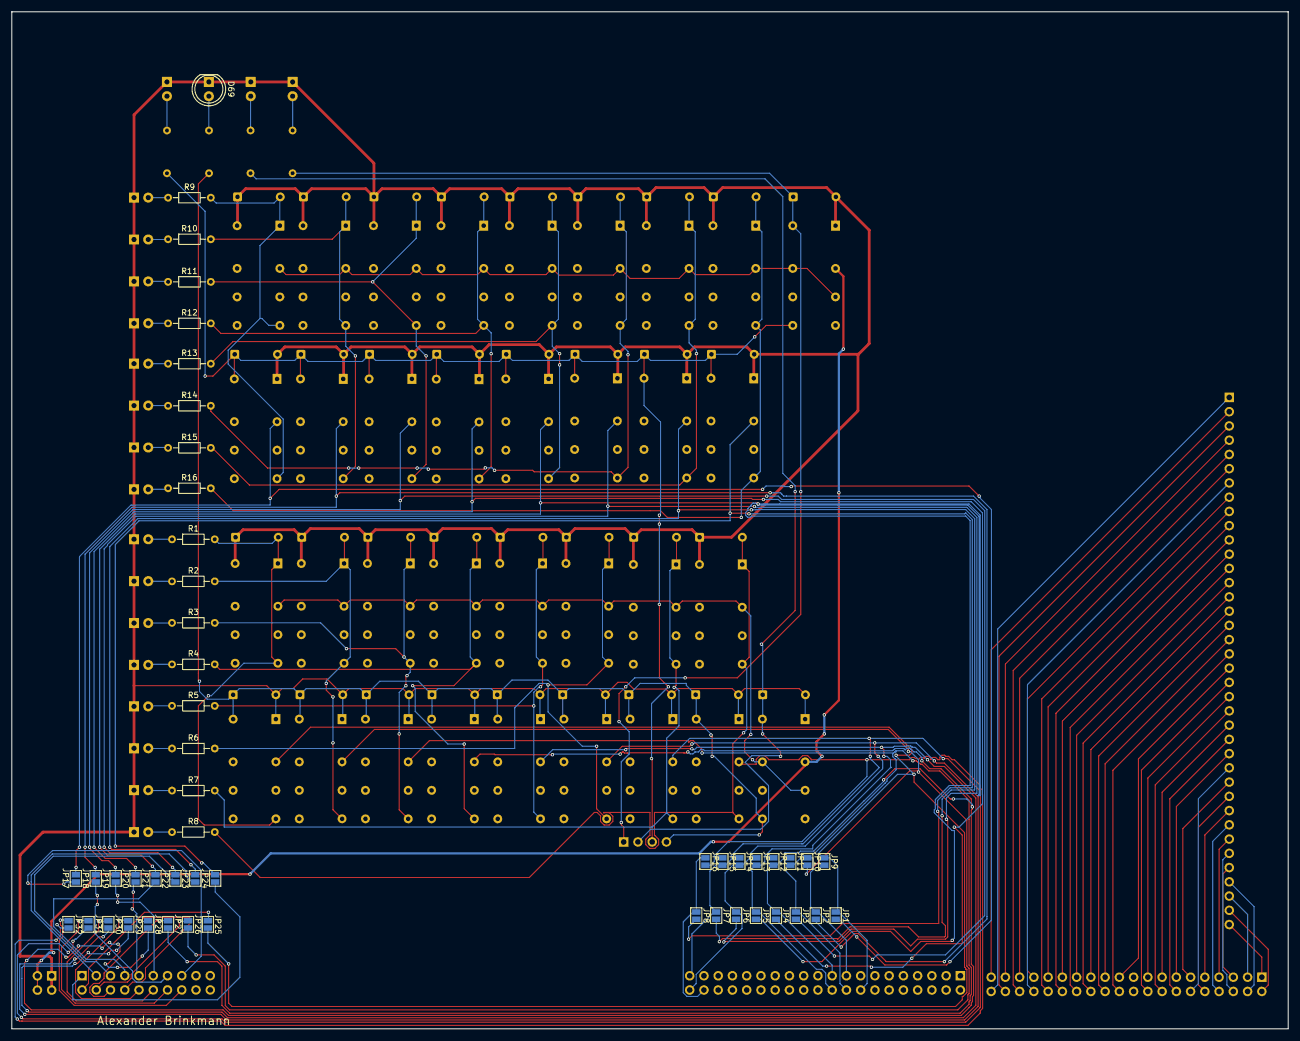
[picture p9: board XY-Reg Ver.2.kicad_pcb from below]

Board: 2 copper layers, 227.6 x 181.3 mm, 146 parts (68 on the bottom side), 122 nets.

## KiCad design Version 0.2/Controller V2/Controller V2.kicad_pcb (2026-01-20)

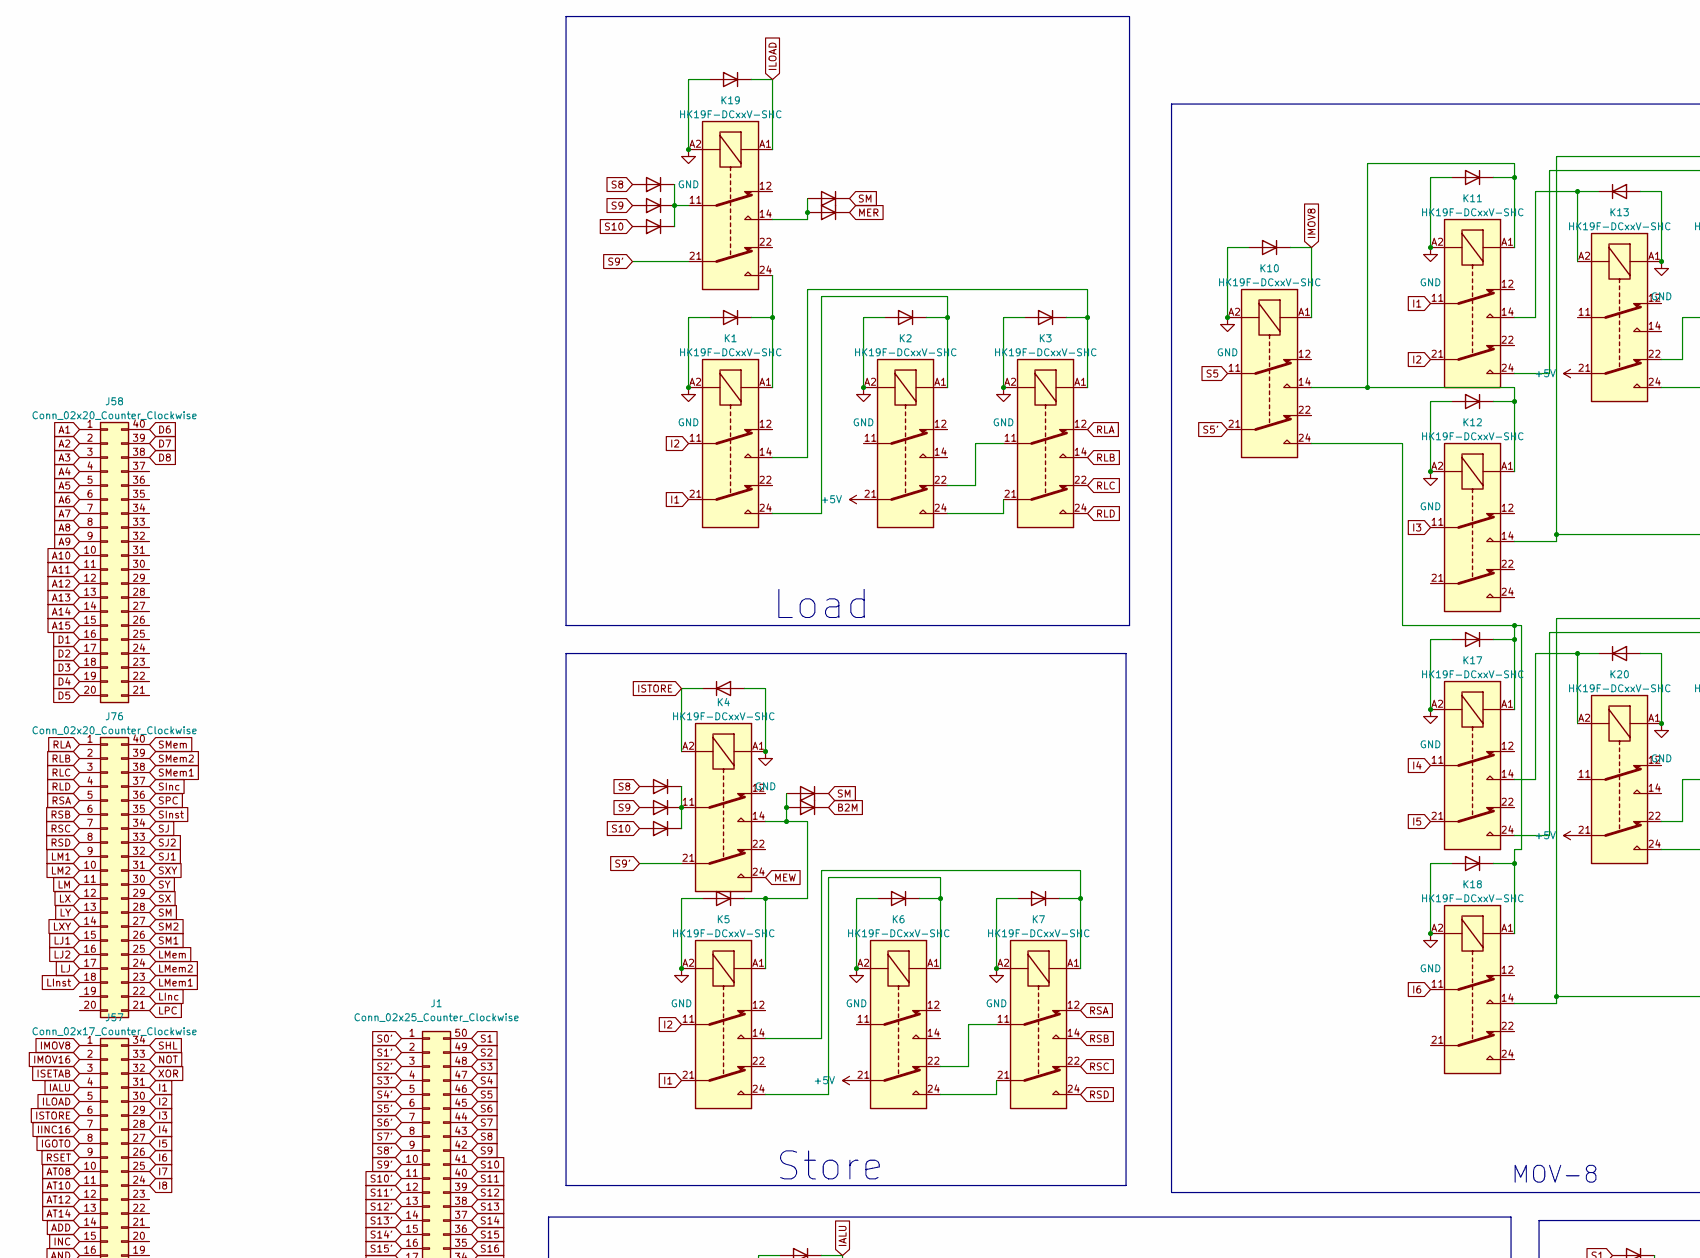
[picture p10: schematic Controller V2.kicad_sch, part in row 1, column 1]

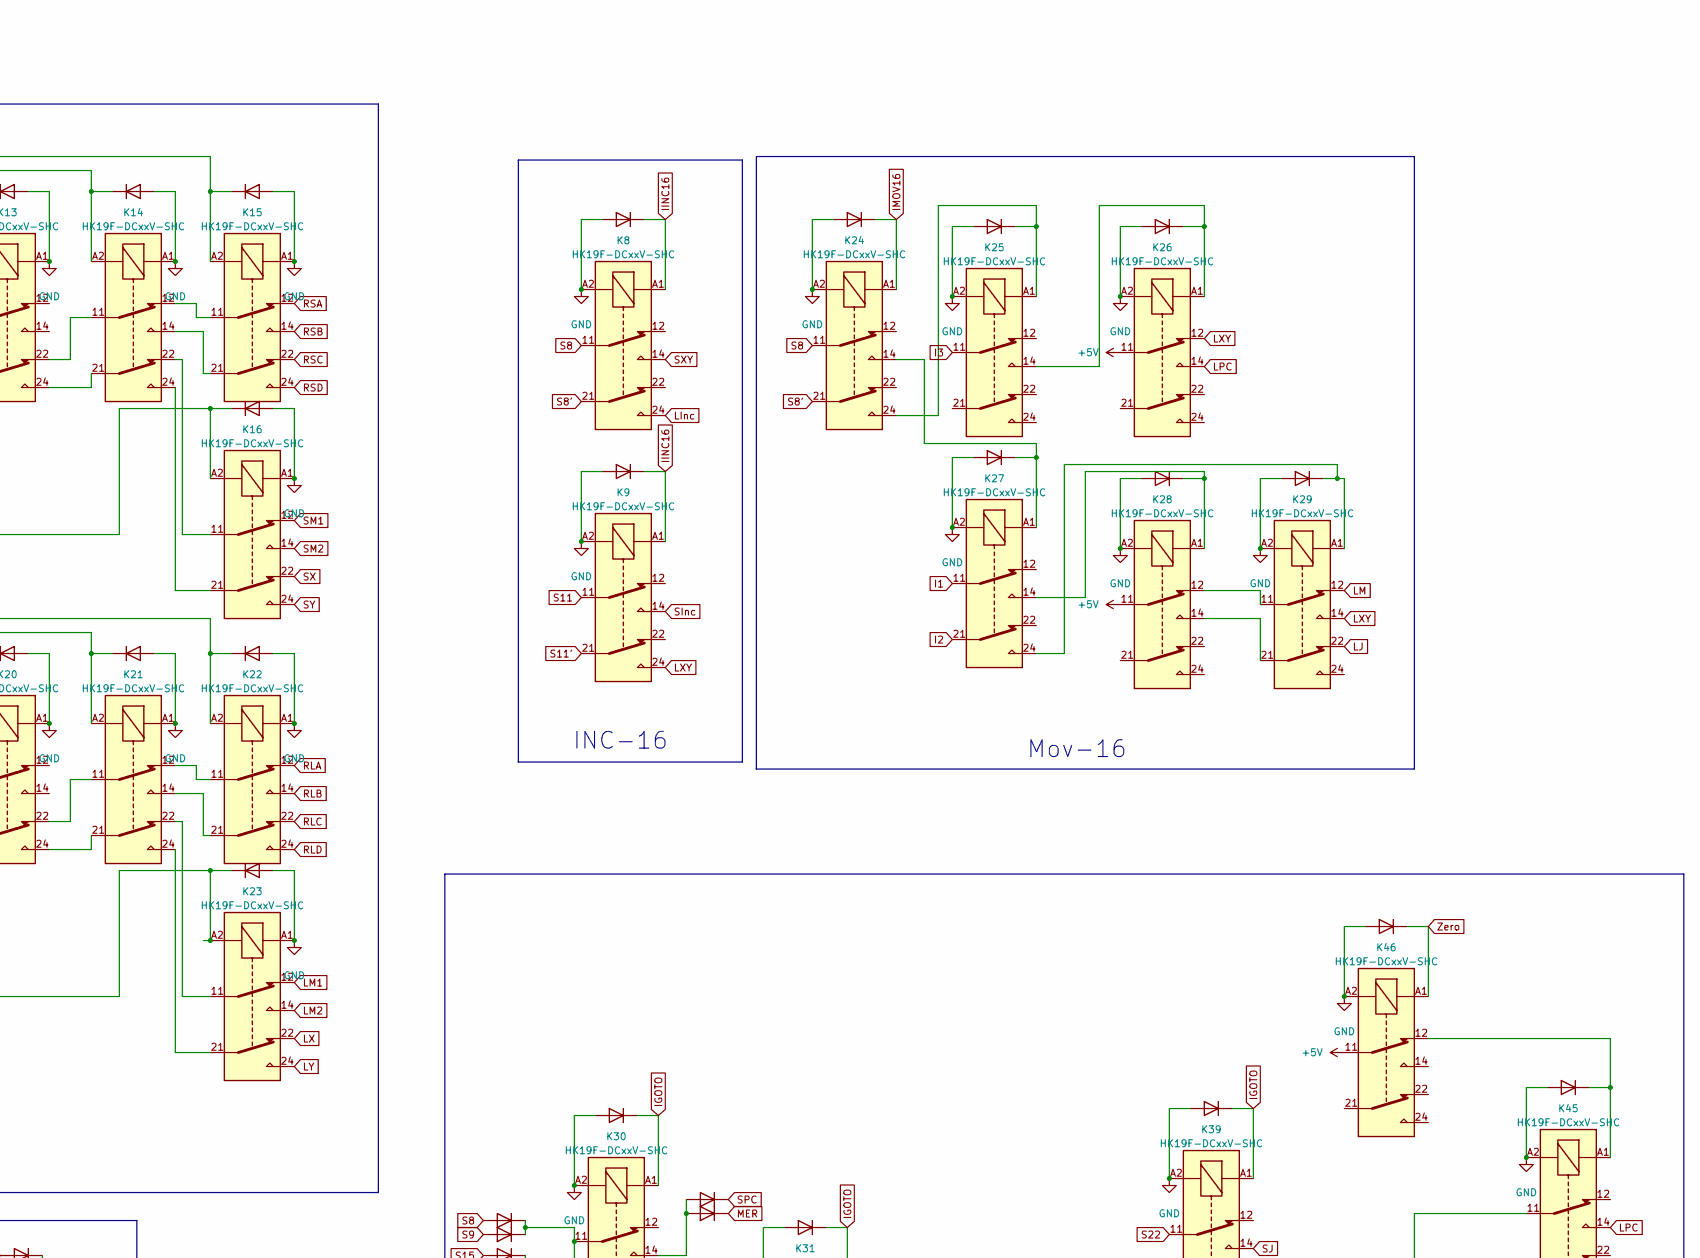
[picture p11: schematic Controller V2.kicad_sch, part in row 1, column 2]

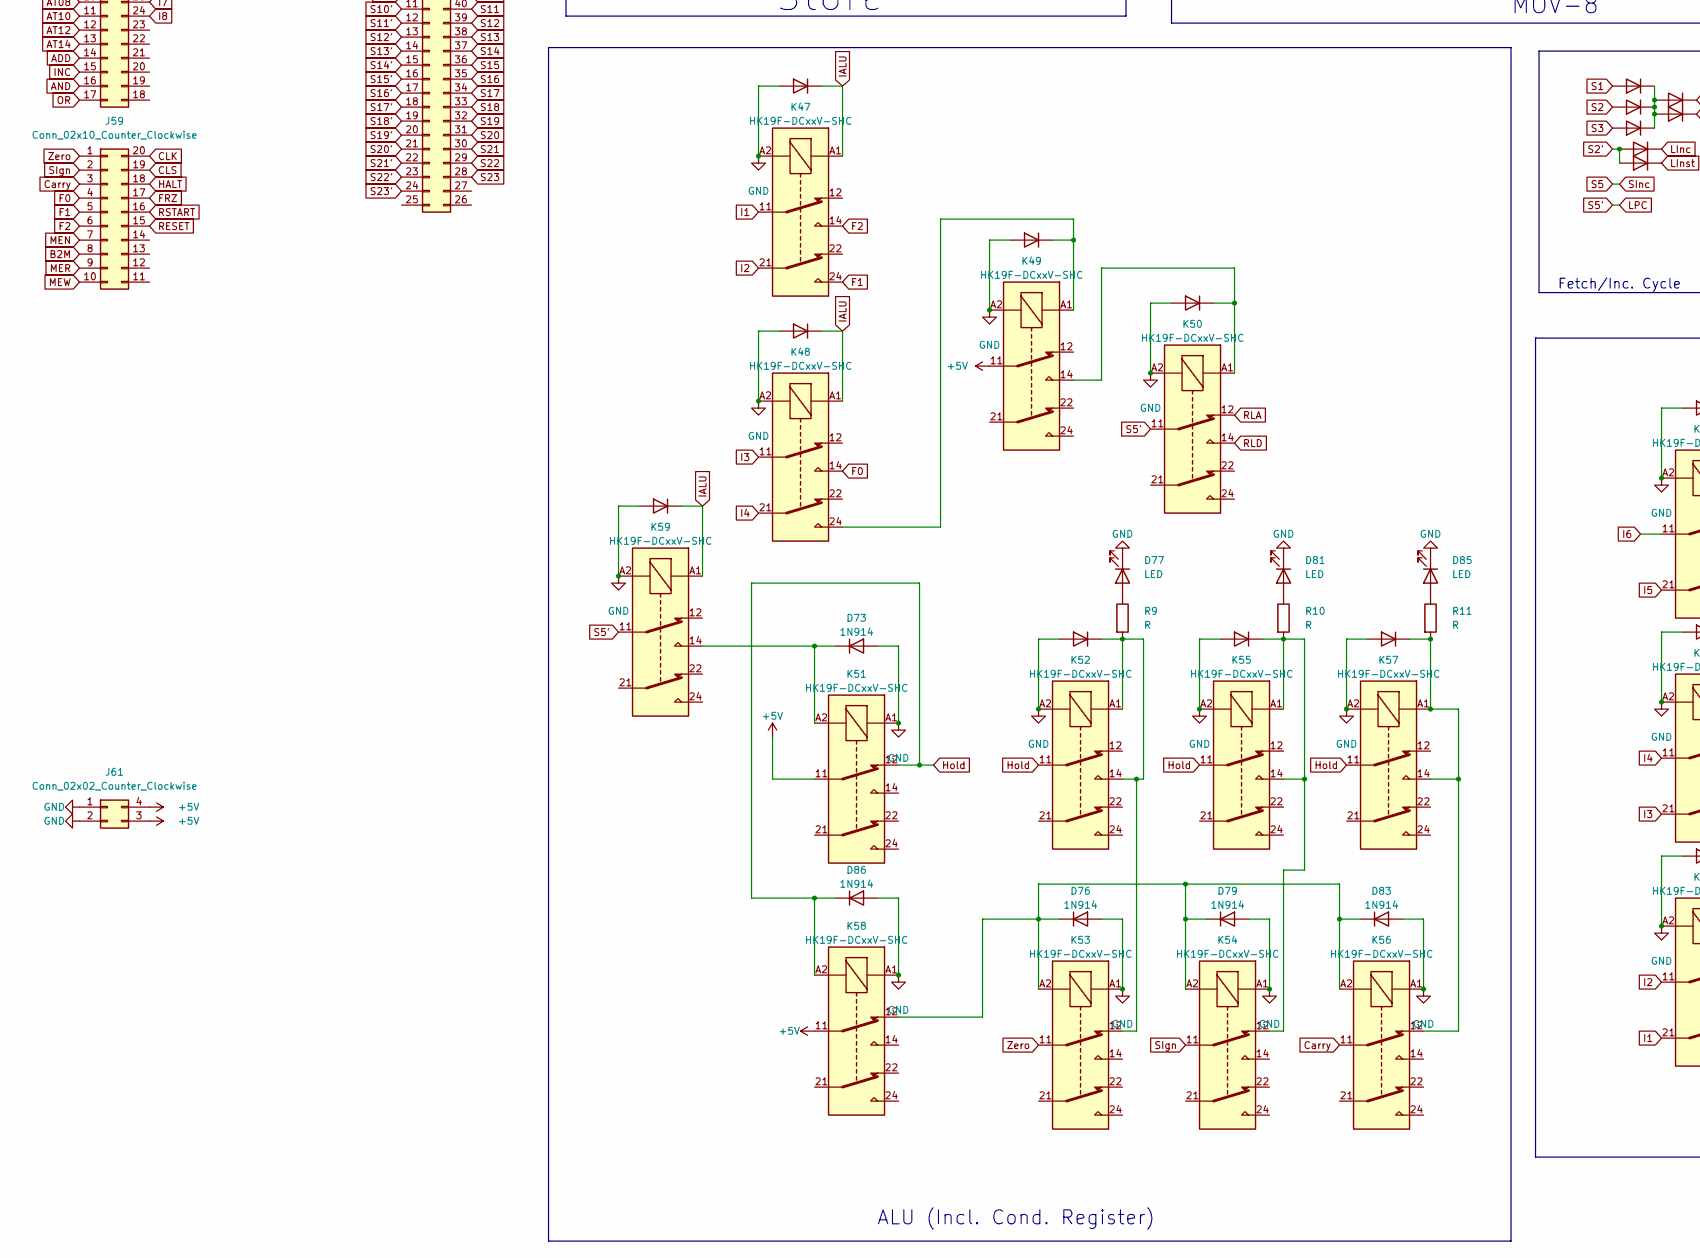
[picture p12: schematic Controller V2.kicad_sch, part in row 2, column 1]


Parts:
D1, D2, D3, D4, D5, D6, D7, D8, D9, D10, D11, D12, D13, D14, D15, D16, D17, D18, D19, D20, D21, D22, D23, D24, D25, D26, D27, D28, D29, D30, D31, D32, D33, D34, D35, D36, D37, D38, D39, D40, D41, D42, D43, D44, D45, D46, D47, D48, D49, D50, D51, D52, D53, D54, D55, D56, D57, D58, D59, D60, D61, D62, D63, D64, D65, D66, D67, D68, D69, D70, D71, D72, D73, D74, D75, D76, D78, D79, D80, D82, D83, D84, D86, D87, D88, D89, D90, D91, D92, D93, D94, D95, D96, D97: 1N914; D_DO-35_SOD27_P7.62mm_Horizontal
D77, D81, D85: LED; LED_D5.0mm ohne SilkS
J1: Conn_02x25_Counter_Clockwise; PinSocket_2x25_P2.54mm_Horizontal
J57: Conn_02x17_Counter_Clockwise; PinSocket_2x17_P2.54mm_Horizontal
J58, J76: Conn_02x20_Counter_Clockwise; PinSocket_2x20_P2.54mm_Horizontal
J59: Conn_02x10_Counter_Clockwise; PinSocket_2x10_P2.54mm_Horizontal
J61: Conn_02x02_Counter_Clockwise; PinSocket_2x02_P2.54mm_Horizontal
K1, K2, K3, K4, K5, K6, K7, K8, K9, K10, K11, K12, K13, K14, K15, K16, K17, K18, K19, K20, K21, K22, K23, K24, K25, K26, K27, K28, K29, K30, K31, K32, K33, K34, K35, K36, K37, K38, K39, K40, K41, K42, K43, K44, K45, K46, K47, K48, K49, K50, K51, K52, K53, K54, K55, K56, K57, K58, K59, K60, K61, K62, K63: HK19F-DCxxV-SHC; Relay_DPDT_Finder_30.22 ohne SilkS
R9, R10, R11: R; R_Axial_DIN0204_L3.6mm_D1.6mm_P7.62mm_Horizontal

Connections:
+5V: J61.3, J61.4, K2.21, K6.21, K13.21, K20.21, K26.11, K28.11, K33.11, K35.11, K46.11, K49.11, K51.11, K58.11, K61.11
A1: J58.1
A2: J58.2
A3: J58.3
A4: J58.4
A5: J58.5
A6: J58.6
A7: J58.7
A8: J58.8
A9: J58.9
A10: J58.10
A11: J58.11
A12: J58.12
A13: J58.13
A14: J58.14
A15: J58.15
ADD: J57.14
AND: J57.16
AT08: J57.10
AT10: J57.11
AT12: J57.12
AT14: J57.13
B2M: D88.1 (K), J59.8
CLK: J59.20
CLS: J59.19
Carry: D64.1 (K), J59.3, K43.A1, K56.11
D1: J58.16, K60.24
D2: J58.17, K62.14
D3: J58.18, K62.24
D4: J58.19, K63.14
D5: J58.20, K63.24
D6: J58.40
D7: J58.39
D8: J58.38
F0: J59.4, K48.14
F1: J59.5, K47.24
F2: J59.6, K47.14
FRZ: J59.17
GND: D1.2 (A), D5.2 (A), D6.2 (A), D10.2 (A), D11.2 (A), D15.2 (A), D16.2 (A), D17.2 (A), D18.2 (A), D19.2 (A), D20.2 (A), D21.2 (A), D22.2 (A), D23.2 (A), D24.2 (A), D25.2 (A), D26.2 (A), D27.2 (A), D28.2 (A), D29.2 (A), D30.2 (A), D31.2 (A), D32.2 (A), D33.2 (A), D34.2 (A), D35.2 (A), D36.2 (A), D37.2 (A), D38.2 (A), D39.2 (A), D44.2 (A), D45.2 (A), D46.2 (A), D47.2 (A), D48.2 (A), D49.2 (A), D54.2 (A), D57.2 (A), D58.2 (A), D59.2 (A), D60.2 (A), D63.2 (A), D64.2 (A), D65.2 (A), D66.2 (A), D67.2 (A), D68.2 (A), D69.2 (A), D70.2 (A), D71.2 (A), D72.2 (A), D73.2 (A), D74.2 (A), D75.2 (A), D76.2 (A), D77.1 (K), D78.2 (A), D79.2 (A), D80.2 (A), D81.1 (K), D82.2 (A), D83.2 (A), D84.2 (A), D85.1 (K), D86.2 (A), D87.2 (A), J61.1, J61.2, K1.A2, K2.A2, K3.A2, K4.A1, K5.A2, K6.A2, K7.A2, K8.A2, K9.A2, K10.A2, K11.A2, K12.A2, K13.A1, K14.A1, K15.A1, K16.A1, K17.A2, K18.A2, K19.A2, K20.A1, K21.A1, K22.A1, K23.A1, K24.A2, K25.A2, K26.A2, K27.A2, K28.A2, K29.A2, K30.A2, K31.A2, K32.A2, K33.A2, K34.A2, K35.A2, K36.A2, K37.A2, K38.A2, K39.A2, K40.A2, K41.A2, K42.A2, K43.A2, K44.A2, K45.A2, K46.A2, K47.A2, K48.A2, K49.A2, K50.A2, K51.A1, K52.A2, K53.A1, K54.A1, K55.A2, K56.A1, K57.A2, K58.A1, K59.A2, K60.A2, K61.A2, K62.A2, K63.A2
HALT: J59.18
Hold: D86.1 (K), K51.12, K52.11, K55.11, K57.11, K58.A2
I1: J57.31, K1.21, K5.21, K11.11, K27.11, K38.11, K47.11, K63.21
I2: J57.30, K1.11, K5.11, K11.21, K27.21, K40.11, K47.21, K63.11
I3: J57.29, K12.11, K25.11, K40.21, K48.11, K62.21
I4: J57.28, K17.11, K41.11, K48.21, K62.11
I5: J57.27, K17.21, K41.21, K60.21
I6: J57.26, K18.11, K60.11
I7: J57.25, K32.11, K34.11
I8: J57.24
IALU: D68.1 (K), D69.1 (K), D74.1 (K), J57.4, K47.A1, K48.A1, K59.A1
IGOTO: D39.1 (K), D44.1 (K), D49.1 (K), D54.1 (K), D58.1 (K), J57.8, K30.A1, K31.A1, K36.A1, K37.A1, K39.A1
IINC16: D20.1 (K), D21.1 (K), J57.7, K8.A1, K9.A1
ILOAD: D19.1 (K), J57.5, K19.A1
IMOV8: D5.1 (K), J57.1, K10.A1
IMOV16: D33.1 (K), J57.2, K24.A1
INC: J57.15
ISETAB: D72.1 (K), D82.1 (K), D87.1 (K), J57.3, K60.A1, K62.A1, K63.A1
ISTORE: D18.1 (K), J57.6, K4.A2
LInc: D62.1 (K), D96.1 (K), J76.22, K8.24
LInst: D97.1 (K), J76.18
LJ1: J76.15, K33.14
LJ2: J76.16, K35.14
LJ: J76.17, K29.22
LM: J76.11, K29.12
LM1: J76.9, K23.12, K33.12
LM2: J76.10, K23.14, K35.12
LMem: J76.25
LMem1: J76.23
LMem2: J76.24
LPC: J1.6, J76.21, K10.21, K26.14, K37.14, K42.14, K43.14, K44.14, K45.14, K50.11, K59.11
LX: J76.12, K23.22
LXY: J76.14, K9.24, K26.12, K29.14, K38.14
LY: J76.13, K23.24
MEN: J59.7
MER: D91.1 (K), D92.1 (K), D95.1 (K), J59.9
MEW: J59.10, K4.24
NOT: J57.33
unnamed: D1.1 (K), K1.A1, K19.24
unnamed: D2.1 (K), D3.1 (K), D4.1 (K), D92.2 (A), D93.2 (A)
unnamed: D7.1 (K), D8.1 (K), D9.1 (K), K19.11
unnamed: D10.1 (K), K1.24, K2.A1
unnamed: D11.1 (K), K1.14, K3.A1
unnamed: D12.1 (K), D13.1 (K), D14.1 (K), K4.11
unnamed: D15.1 (K), D88.2 (A), D89.2 (A), K4.14, K5.A1
unnamed: D16.1 (K), K5.24, K6.A1
unnamed: D17.1 (K), K5.14, K7.A1
unnamed: D6.1 (K), D22.1 (K), K10.14, K11.A1, K12.A1
unnamed: D23.1 (K), K11.14, K13.A2
unnamed: D24.1 (K), K11.24, K14.A2
unnamed: D25.1 (K), D26.1 (K), K12.14, K15.A2, K16.A2
unnamed: D27.1 (K), D28.1 (K), K10.24, K17.A1, K18.A1
unnamed: D29.1 (K), K17.14, K20.A2
unnamed: D30.1 (K), K17.24, K21.A2
unnamed: D31.1 (K), D32.1 (K), K18.14, K22.A2, K23.A2
unnamed: D34.1 (K), K24.24, K25.A1
unnamed: D35.1 (K), K25.14, K26.A1
unnamed: D36.1 (K), K24.14, K27.A1
unnamed: D37.1 (K), K27.14, K28.A1
unnamed: D38.1 (K), K27.24, K29.A1
unnamed: D40.1 (K), D41.1 (K), D42.1 (K), D43.1 (K), K30.11
unnamed: D45.1 (K), K31.14, K32.A1
unnamed: D46.1 (K), K32.14, K33.A1
unnamed: D47.1 (K), K31.24, K34.A1
unnamed: D48.1 (K), K34.14, K35.A1
unnamed: D50.1 (K), D51.1 (K), K36.11
unnamed: D52.1 (K), D53.1 (K), K36.21
unnamed: D55.1 (K), D56.1 (K), K37.11
unnamed: D57.1 (K), K37.24, K38.A1
unnamed: D59.1 (K), D60.1 (K), K39.24, K40.A1, K41.A1
unnamed: D61.2 (A), K36.24
unnamed: D62.2 (A), K36.14
unnamed: D66.1 (K), K45.A1, K46.12
unnamed: D70.1 (K), K48.24, K49.A1
unnamed: D71.1 (K), K49.14, K50.A1
unnamed: D73.1 (K), K51.A2, K59.14
unnamed: D75.1 (K), K52.14, K52.A1, K53.12, R9.2
unnamed: D76.1 (K), D79.1 (K), D83.1 (K), K53.A2, K54.A2, K56.A2, K58.12
unnamed: D77.2 (A), R9.1
unnamed: D78.1 (K), K60.14, K61.A1
unnamed: D80.1 (K), K54.12, K55.14, K55.A1, R10.2
unnamed: D81.2 (A), R10.1
unnamed: D84.1 (K), K56.12, K57.14, K57.A1, R11.2
unnamed: D85.2 (A), R11.1
unnamed: D90.2 (A), D91.2 (A), K19.14
unnamed: D94.2 (A), D95.2 (A), K30.14
unnamed: K2.22, K3.11
unnamed: K2.24, K3.21
unnamed: K6.22, K7.11
unnamed: K6.24, K7.21
unnamed: K13.22, K14.11
unnamed: K13.24, K14.21
unnamed: K14.12, K15.11
unnamed: K14.14, K15.21
unnamed: K14.22, K16.11
unnamed: K14.24, K16.21
unnamed: K20.22, K21.11
unnamed: K20.24, K21.21
unnamed: K21.12, K22.11
unnamed: K21.14, K22.21
unnamed: K21.22, K23.11
unnamed: K21.24, K23.21
unnamed: K28.12, K29.11
unnamed: K28.14, K29.21
unnamed: K40.14, K45.11
unnamed: K40.24, K42.11
unnamed: K41.14, K43.11
unnamed: K41.24, K44.11
OR: J57.17
RESET: J59.15
RLA: J76.1, K3.12, K22.12, K50.12, K61.12
RLB: J76.2, K3.14, K22.14, K61.14
RLC: J76.3, K3.22, K22.22
RLD: J76.4, K3.24, K22.24, K50.14
RSA: J76.5, K7.12, K15.12
RSB: J76.6, K7.14, K15.14
RSC: J76.7, K7.22, K15.22
RSD: J76.8, K7.24, K15.24
RSET: J57.9
RSTART: J59.16
S0': J1.1
S1: D2.2 (A), J1.50
S1': J1.2
S2: D3.2 (A), J1.49
S2': D96.2 (A), D97.2 (A), J1.3
S3: D4.2 (A), J1.48
S3': J1.4
S4: J1.47
S4': J1.5
S5: D61.1 (K), J1.46, J76.37, K9.14, K10.11
S6: J1.45
S6': J1.7
S7: J1.44
S7': J1.8
S8: D7.2 (A), D12.2 (A), D40.2 (A), J1.43, K8.11, K24.11
S8': J1.9, K8.21, K24.21
S9: D8.2 (A), D13.2 (A), D41.2 (A), J1.42
S9': D50.2 (A), J1.10, K4.21, K19.21, K31.11
S10: D9.2 (A), D14.2 (A), J1.41
S10': J1.11
S11: J1.40, K9.11
S11': J1.12, K9.21
S12: D52.2 (A), J1.39
S12': D55.2 (A), J1.13
S13: J1.38
S13': J1.14
S14: J1.37
S14': J1.15
S15: D42.2 (A), J1.36
S15': J1.16
S16: D43.2 (A), J1.35
S16': D51.2 (A), J1.17, K31.21
S17: J1.34
S17': J1.18
S18: J1.33
S18': J1.19
S19: D53.2 (A), J1.32
S19': D56.2 (A), J1.20, K37.21
S20: J1.31
S20': J1.21
S21: J1.30
S21': J1.22
S22: J1.29, K39.11
S22': J1.23, K39.21
S23: J1.28
S23': J1.24
SHL: J57.34
SIgn: D65.1 (K), J59.2, K44.A1, K54.11
SInst: J76.35
SJ1: J76.32
SJ2: J76.33
SJ: J76.34, K39.14
SM: D89.1 (K), D90.1 (K), J76.28
SM1: J76.26, K16.12
SM2: J76.27, K16.14
SMem: J76.40
SMem1: J76.38
SMem2: J76.39
SPC: D93.1 (K), D94.1 (K), J76.36
SX: J76.29, K16.22
SXY: J76.31, K8.14
SY: J76.30, K16.24
XOR: J57.32
Zero: D63.1 (K), D67.1 (K), J59.1, K42.A1, K46.A1, K53.11

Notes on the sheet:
SET AB
Fetch/Inc. Cycle
ALU (Incl. Cond. Register)
Cond. GOTO
Load
Mov-16
MOV-8
INC-16
Store


Board: 2 copper layers, 231.2 x 156.8 mm, 169 parts (0 on the bottom side), 151 nets.

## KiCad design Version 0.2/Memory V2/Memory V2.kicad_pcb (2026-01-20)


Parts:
C1, C2: C; C_Radial_D6.3mm_H5.0mm_P2.50mm
D1, D2, D3, D4, D5, D6, D7, D8, D9, D10, D11, D12, D13, D14, D15, D16, D17, D18, D19, D20, D21, D22, D23, D24, D25, D26, D27, D28, D29, D30, D31, D32, D33, D34: 1N914; D_DO-35_SOD27_P7.62mm_Horizontal
D35, D36, D37, D38, D39, D40, D41, D42, D43, D44, D45, D46, D47, D48, D49, D50, D51, D52, D53, D54, D55, D56, D57, D58: LED; LED_D5.0mm ohne SilkS
J58: Conn_02x20_Counter_Clockwise; PinSocket_2x20_P2.54mm_Horizontal
J59: Conn_02x10_Counter_Clockwise; PinSocket_2x10_P2.54mm_Horizontal
J61: Conn_02x02_Counter_Clockwise; PinSocket_2x02_P2.54mm_Horizontal
K1, K2, K3, K4, K5, K6, K7, K8, K9, K10, K16, K17, K18, K19, K20, K21, K22, K23, K24, K25, K26, K27, K28, K29, K30, K31: HK19F-DCxxV-SHC; Relay_DPDT_Finder_30.22
R1, R2: R; R_Axial_DIN0207_L6.3mm_D2.5mm_P10.16mm_Horizontal
R3, R4, R5, R6, R7, R8, R9, R10, R11, R12, R13, R14, R15, R16, R17, R18, R19, R20, R21, R22, R23, R24, R25, R26: R; R_Axial_DIN0207_L6.3mm_D2.5mm_P2.54mm_Vertical
U1: ULN2803A; DIP-18_W7.62mm
U2: CY62256-70PC; DIP-28_W15.24mm

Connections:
#OE: K9.11, K10.11, R2.1, U2.22 (~OE)
#WE: K9.21, R1.1, U2.27 (~WE)
+5V: C1.2, C2.2, J61.3, J61.4, K16.11, K17.11, K20.11, K21.11, K24.11, K25.11, K28.11, K29.11, R1.2, R2.2, U1.10 (COM), U2.28 (VCC)
A1: J58.1, R12.2, U2.10 (A0)
A2: J58.2, R13.2, U2.9 (A1)
A3: J58.3, R14.2, U2.8 (A2)
A4: J58.4, R15.2, U2.7 (A3)
A5: J58.5, R16.2, U2.6 (A4)
A6: J58.6, R17.2, U2.5 (A5)
A7: J58.7, R18.2, U2.4 (A6)
A8: J58.8, R19.2, U2.3 (A7)
A9: J58.9, R20.2, U2.25 (A8)
A10: J58.10, R21.2, U2.24 (A9)
A11: J58.11, R22.2, U2.21 (A10)
A12: J58.12, R23.2, U2.23 (A11)
A13: J58.13, R24.2, U2.2 (A12)
A14: J58.14, R25.2, U2.26 (A13)
A15: J58.15, R26.2, U2.1 (A14)
B2M: D9.1 (K), D10.1 (K), D11.1 (K), D12.1 (K), D13.1 (K), D14.1 (K), D15.1 (K), D32.1 (K), J59.8, K1.A2, K2.A2, K3.A2, K4.A2, K5.A2, K6.A2, K7.A2, K8.A2, R3.2
CLK: J59.20
CLS: J59.19
Carry: J59.3
D1: J58.16, K1.11, K18.11
D2: J58.17, K2.11, K22.11
D3: J58.18, K3.11, K26.11
D4: J58.19, K4.11, K30.11
D5: J58.20, K5.11, K19.11
D6: J58.40, K6.11, K23.11
D7: J58.39, K7.11, K27.11
D8: J58.38, K8.11, K31.11
DI1: D1.2 (A), K16.14
DI2: D2.2 (A), K20.14
DI3: D3.2 (A), K24.14
DI4: D4.2 (A), K28.14
DI5: D5.2 (A), K17.14
DI6: D6.2 (A), K21.14
DI7: D7.2 (A), K25.14
DI8: D8.2 (A), K29.14
DO1: K18.14, U1.18 (O1)
DO2: K22.14, U1.17 (O2)
DO3: K26.14, U1.16 (O3)
DO4: K30.14, U1.15 (O4)
DO5: K19.14, U1.14 (O5)
DO6: K23.14, U1.13 (O6)
DO7: K27.14, U1.12 (O7)
DO8: K31.14, U1.11 (O8)
F0: J59.4
F1: J59.5
F2: J59.6
FRZ: J59.17
GND: C1.1, C2.1, D9.2 (A), D10.2 (A), D11.2 (A), D12.2 (A), D13.2 (A), D14.2 (A), D15.2 (A), D16.2 (A), D17.2 (A), D18.2 (A), D19.2 (A), D20.2 (A), D21.2 (A), D22.2 (A), D23.2 (A), D24.2 (A), D25.2 (A), D26.2 (A), D27.2 (A), D28.2 (A), D29.2 (A), D30.2 (A), D31.2 (A), D32.2 (A), D33.2 (A), D34.2 (A), D35.1 (K), D36.1 (K), D37.1 (K), D38.1 (K), D39.1 (K), D40.1 (K), D41.1 (K), D42.1 (K), D43.1 (K), D44.1 (K), D45.1 (K), D46.1 (K), D47.1 (K), D48.1 (K), D49.1 (K), D50.1 (K), D51.1 (K), D52.1 (K), D53.1 (K), D54.1 (K), D55.1 (K), D56.1 (K), D57.1 (K), D58.1 (K), J61.1, J61.2, K1.A1, K2.A1, K3.A1, K4.A1, K5.A1, K6.A1, K7.A1, K8.A1, K9.14, K9.24, K9.A1, K10.14, K10.A1, K16.A1, K17.A1, K18.A1, K19.A1, K20.A1, K21.A1, K22.A1, K23.A1, K24.A1, K25.A1, K26.A1, K27.A1, K28.A1, K29.A1, K30.A1, K31.A1, U1.9 (GND), U2.14 (GND), U2.20 (~CS)
HALT: J59.18
MEN: J59.7
MER: D18.1 (K), D19.1 (K), D22.1 (K), D23.1 (K), D26.1 (K), D27.1 (K), D30.1 (K), D31.1 (K), D34.1 (K), J59.9, K10.A2, K18.A2, K19.A2, K22.A2, K23.A2, K26.A2, K27.A2, K30.A2, K31.A2
MEW: D33.1 (K), J59.10, K9.A2
unnamed: D16.1 (K), K1.14, K16.A2
unnamed: D17.1 (K), K5.14, K17.A2
unnamed: D20.1 (K), K2.14, K20.A2
unnamed: D21.1 (K), K6.14, K21.A2
unnamed: D24.1 (K), K3.14, K24.A2
unnamed: D25.1 (K), K7.14, K25.A2
unnamed: D28.1 (K), K4.14, K28.A2
unnamed: D29.1 (K), K8.14, K29.A2
unnamed: D35.2 (A), R4.1
unnamed: D36.2 (A), R5.1
unnamed: D37.2 (A), R6.1
unnamed: D38.2 (A), R7.1
unnamed: D39.2 (A), R8.1
unnamed: D40.2 (A), R9.1
unnamed: D41.2 (A), R10.1
unnamed: D42.2 (A), R11.1
unnamed: D43.2 (A), R12.1
unnamed: D44.2 (A), R13.1
unnamed: D45.2 (A), R14.1
unnamed: D46.2 (A), R15.1
unnamed: D47.2 (A), R16.1
unnamed: D48.2 (A), R17.1
unnamed: D49.2 (A), R18.1
unnamed: D50.2 (A), R19.1
unnamed: D51.2 (A), R20.1
unnamed: D52.2 (A), R21.1
unnamed: D53.2 (A), R22.1
unnamed: D54.2 (A), R23.1
unnamed: D55.2 (A), R24.1
unnamed: D56.2 (A), R25.1
unnamed: D57.2 (A), R26.1
unnamed: D58.2 (A), R3.1
Q0: D1.1 (K), R4.2, U1.1 (I1), U2.11 (Q0)
Q1: D2.1 (K), R5.2, U1.2 (I2), U2.12 (Q1)
Q2: D3.1 (K), R6.2, U1.3 (I3), U2.13 (Q2)
Q3: D4.1 (K), R7.2, U1.4 (I4), U2.15 (Q3)
Q4: D5.1 (K), R8.2, U1.5 (I5), U2.16 (Q4)
Q5: D6.1 (K), R9.2, U1.6 (I6), U2.17 (Q5)
Q6: D7.1 (K), R10.2, U1.7 (I7), U2.18 (Q6)
Q7: D8.1 (K), R11.2, U1.8 (I8), U2.19 (Q7)
RESET: J59.15
RSTART: J59.16
SIgn: J59.2
Zero: J59.1

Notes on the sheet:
Write = #OE LOW, #WE LOW Read = #OE LOW, #WE HIGH


Board: 2 copper layers, 162.6 x 148.0 mm, 117 parts (0 on the bottom side), 86 nets.

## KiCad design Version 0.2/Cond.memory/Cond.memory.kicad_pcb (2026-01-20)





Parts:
C1, C2, C3, C4, C5, C6, C7, C8, C9, C10, C11, C12, C13, C14, C15, C16, C17, C18, C19, C20, C21, C22, C23, C24, C25, C26, C27, C28, C29, C30, C31, C32, C33, C34, C35, C36, C37, C38, C39, C40, C41, C42, C43, C44, C45, C46, C47, C48, C49, C50, C51, C52, C53, C54, C55, C56, C57, C58, C59, C60, C61, C62, C63, C64, C65, C66, C67, C68, C69, C70, C71, C72, C73, C74, C75, C76, C77, C78, C79, C80, C81, C82, C83, C84, C85, C86, C87, C88, C89, C90, C91, C92, C93, C94, C95, C96, C97, C98, C99, C100, C101, C102, C103, C104, C105, C106, C107, C108, C109, C110, C111, C112, C113, C114, C115, C116, C117, C118, C119, C120: C; C_Radial_D10.0mm_H12.5mm_P5.00mm
D0, D1, D2, D3, D4, D5, D6, D7, D8, D9, D10, D11, D12, D13, D14, D15, D16, D17, D18, D19, D20, D21, D22, D23, D24, D25, D26, D27, D28, D29, D30, D31, D32, D33, D34, D35, D36, D37, D38, D39, D40, D41, D42, D43, D44, D45, D46, D47, D48, D49, D50, D51, D52, D53, D54, D55, D56, D57, D58, D59, D60, D61, D62, D63, D64, D65, D66, D67, D68, D69, D70, D71, D72, D73, D74, D75, D76, D77, D78, D79, D80, D81, D82, D83, D84, D85, D86, D87, D88, D89, D90, D91, D92, D93, D94, D95, D96, D97, D98, D99, D100, D101, D102, D103, D104, D105, D106, D107, D108, D109, D110, D111, D112, D113, D114, D115, D116, D117, D118, D119, D120, D121, D122, D123, D124, D125, D126, D127, D128, D129, D130, D131, D132, D133, D134, D135, D136, D137, D138, D139, D140, D141, D142, D143, D144, D145, D146, D147, D148, D149, D150, D151, D152, D153, D154, D155, D156, D157, D158, D159, D160, D161, D162, D163, D164, D165, D166, D167, D168, D169, D170, D171, D172, D173, D174, D175, D176, D177, D178, D179, D180, D181, D182, D183, D184, D185, D186, D187, D188, D189, D190, D191, D192, D193, D194, D195, D196, D197, D198, D199, D200, D201, D202, D203, D204, D205, D206, D207, D208, D209, D210, D211, D212, D213, D214, D215, D216, D217, D218, D219, D220, D221, D222, D223, D224, D225, D226, D227, D228, D229, D230, D231, D232, D233, D234, D235, D236, D237, D238, D239, D240, D241, D242, D243, D244, D245, D246, D247, D248, D249, D250, D251, D252, D253, D254, D255, D256, D257, D258, D259: 1N914; D_DO-35_SOD27_P7.62mm_Horizontal
J51: Conn_02x10_Counter_Clockwise; PinSocket_2x10_P2.54mm_Vertical
J57: Conn_02x17_Counter_Clockwise; PinSocket_2x17_P2.54mm_Vertical
J58: Conn_02x20_Counter_Clockwise; PinSocket_2x20_P2.54mm_Vertical
J60: Conn_02x10_Odd_Even; PinSocket_2x10_P2.54mm_Vertical
J61: Conn_02x02_Counter_Clockwise; PinSocket_2x02_P2.54mm_Vertical
K1, K2, K3, K4, K5, K6, K7, K8, K9, K10, K11, K12: HK19F-DCxxV-SHC; Relay_DPDT_Finder_30.22 ohne SilkS

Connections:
A1: J58.1, K5.11; also elsewhere on the board
A2: J58.2, K5.21; also elsewhere on the board
A3: J58.3, K6.11; also elsewhere on the board
A4: J58.4, K6.21; also elsewhere on the board
A5: J58.5, K7.11; also elsewhere on the board
A6: J58.6, K7.21; also elsewhere on the board
A7: J58.7, K8.11; also elsewhere on the board
A8: J58.8, K8.21; also elsewhere on the board
A9: J58.9, K4.11; also elsewhere on the board
A10: J58.10, K4.21; also elsewhere on the board
A11: J58.11, K3.11; also elsewhere on the board
A12: J58.12, K3.21; also elsewhere on the board
A13: J58.13, K2.11; also elsewhere on the board
A14: J58.14, K2.21; also elsewhere on the board
A15: J58.15, K1.11; also elsewhere on the board
B2M: D248.1 (K), D249.1 (K), D250.1 (K), D251.1 (K), J51.8, K9.A2, K10.A2, K11.A2, K12.A2
CLK: J51.20
CLS: J51.19
Carry: J51.3
D1: D256.1 (K), J58.16, K9.14; also elsewhere on the board
D2: D257.1 (K), J58.17, K9.24; also elsewhere on the board
D3: D258.1 (K), J58.18, K10.14; also elsewhere on the board
D4: D259.1 (K), J58.19, K10.24; also elsewhere on the board
D5: D254.1 (K), J58.20, K11.14; also elsewhere on the board
D6: D255.1 (K), J58.40, K11.24; also elsewhere on the board
D7: D253.1 (K), J58.39, K12.14; also elsewhere on the board
D8: D252.1 (K), J58.38, K12.24; also elsewhere on the board
F0: J51.4
F1: J51.5
F2: J51.6
FRZ: J51.17
GND: D0.2 (A), D1.2 (A), D2.2 (A), D3.2 (A), D4.2 (A), D5.2 (A), D6.2 (A), D7.2 (A), D248.2 (A), D249.2 (A), D250.2 (A), D251.2 (A), J61.1, J61.2, K1.A1, K2.A1, K3.A1, K4.A1, K5.A1, K6.A1, K7.A1, K8.A1, K9.A1, K10.A1, K11.A1, K12.A1; also elsewhere on the board
HALT: J51.18
MEN: D0.1 (K), D1.1 (K), D2.1 (K), D3.1 (K), D4.1 (K), D5.1 (K), D6.1 (K), D7.1 (K), J51.7, K1.A2, K2.A2, K3.A2, K4.A2, K5.A2, K6.A2, K7.A2, K8.A2
MER: J51.9
MEW: J51.10
unnamed: C1.1, D8.1 (K), D9.2 (A)
unnamed: D8.2 (A), D10.2 (A), D12.2 (A), D14.2 (A), D16.2 (A), D18.2 (A), D20.2 (A), D22.2 (A), K5.12
unnamed: C2.1, D10.1 (K), D11.2 (A)
unnamed: D9.1 (K), D11.1 (K), D13.1 (K), D15.1 (K), D17.1 (K), D19.1 (K), D21.1 (K), D23.1 (K), K5.14
unnamed: C3.1, D12.1 (K), D13.2 (A)
unnamed: C4.1, D14.1 (K), D15.2 (A)
unnamed: C5.1, D16.1 (K), D17.2 (A)
unnamed: C6.1, D18.1 (K), D19.2 (A)
unnamed: C7.1, D20.1 (K), D21.2 (A)
unnamed: C8.1, D22.1 (K), D23.2 (A)
unnamed: D24.2 (A), D26.2 (A), D28.2 (A), D30.2 (A), D32.2 (A), D34.2 (A), D36.2 (A), D38.2 (A), K5.22
unnamed: C9.1, D24.1 (K), D25.2 (A)
unnamed: D25.1 (K), D27.1 (K), D29.1 (K), D31.1 (K), D33.1 (K), D35.1 (K), D37.1 (K), D39.1 (K), K5.24
unnamed: C10.1, D26.1 (K), D27.2 (A)
unnamed: C11.1, D28.1 (K), D29.2 (A)
unnamed: C12.1, D30.1 (K), D31.2 (A)
unnamed: C13.1, D32.1 (K), D33.2 (A)
unnamed: C14.1, D34.1 (K), D35.2 (A)
unnamed: C15.1, D36.1 (K), D37.2 (A)
unnamed: C16.1, D38.1 (K), D39.2 (A)
unnamed: D40.2 (A), D42.2 (A), D44.2 (A), D46.2 (A), D48.2 (A), D50.2 (A), D52.2 (A), D54.2 (A), K6.12
unnamed: C17.1, D40.1 (K), D41.2 (A)
unnamed: D41.1 (K), D43.1 (K), D45.1 (K), D47.1 (K), D49.1 (K), D51.1 (K), D53.1 (K), D55.1 (K), K6.14
unnamed: C18.1, D42.1 (K), D43.2 (A)
unnamed: C19.1, D44.1 (K), D45.2 (A)
unnamed: C20.1, D46.1 (K), D47.2 (A)
unnamed: C21.1, D48.1 (K), D49.2 (A)
unnamed: C22.1, D50.1 (K), D51.2 (A)
unnamed: C23.1, D52.1 (K), D53.2 (A)
unnamed: C24.1, D54.1 (K), D55.2 (A)
unnamed: D56.2 (A), D58.2 (A), D60.2 (A), D62.2 (A), D64.2 (A), D66.2 (A), D68.2 (A), D70.2 (A), K6.22
unnamed: C25.1, D56.1 (K), D57.2 (A)
unnamed: D57.1 (K), D59.1 (K), D61.1 (K), D63.1 (K), D65.1 (K), D67.1 (K), D69.1 (K), D71.1 (K), K6.24
unnamed: C26.1, D58.1 (K), D59.2 (A)
unnamed: C27.1, D60.1 (K), D61.2 (A)
unnamed: C28.1, D62.1 (K), D63.2 (A)
unnamed: C29.1, D64.1 (K), D65.2 (A)
unnamed: C30.1, D66.1 (K), D67.2 (A)
unnamed: C31.1, D68.1 (K), D69.2 (A)
unnamed: C32.1, D70.1 (K), D71.2 (A)
unnamed: D72.2 (A), D74.2 (A), D76.2 (A), D78.2 (A), D80.2 (A), D82.2 (A), D84.2 (A), D86.2 (A), K7.12
unnamed: C33.1, D72.1 (K), D73.2 (A)
unnamed: D73.1 (K), D75.1 (K), D77.1 (K), D79.1 (K), D81.1 (K), D83.1 (K), D85.1 (K), D87.1 (K), K7.14
unnamed: C35.1, D74.1 (K), D75.2 (A)
unnamed: C37.1, D76.1 (K), D77.2 (A)
unnamed: C39.1, D78.1 (K), D79.2 (A)
unnamed: C41.1, D80.1 (K), D81.2 (A)
unnamed: C43.1, D82.1 (K), D83.2 (A)
unnamed: C45.1, D84.1 (K), D85.2 (A)
unnamed: C47.1, D86.1 (K), D87.2 (A)
unnamed: C34.1, D88.1 (K), D89.2 (A)
unnamed: C36.1, D90.1 (K), D91.2 (A)
unnamed: C38.1, D92.1 (K), D93.2 (A)
unnamed: C40.1, D94.1 (K), D95.2 (A)
unnamed: C42.1, D96.1 (K), D97.2 (A)
unnamed: C44.1, D98.1 (K), D99.2 (A)
unnamed: D88.2 (A), D90.2 (A), D92.2 (A), D94.2 (A), D96.2 (A), D98.2 (A), D100.2 (A), D102.2 (A), K7.22
unnamed: C46.1, D100.1 (K), D101.2 (A)
unnamed: D89.1 (K), D91.1 (K), D93.1 (K), D95.1 (K), D97.1 (K), D99.1 (K), D101.1 (K), D103.1 (K), K7.24
unnamed: C48.1, D102.1 (K), D103.2 (A)
unnamed: D104.2 (A), D106.2 (A), D108.2 (A), D110.2 (A), D112.2 (A), D114.2 (A), D116.2 (A), D118.2 (A), K8.12
unnamed: C49.1, D104.1 (K), D105.2 (A)
unnamed: D105.1 (K), D107.1 (K), D109.1 (K), D111.1 (K), D113.1 (K), D115.1 (K), D117.1 (K), D119.1 (K), K8.14
unnamed: C51.1, D106.1 (K), D107.2 (A)
unnamed: C53.1, D108.1 (K), D109.2 (A)
unnamed: C55.1, D110.1 (K), D111.2 (A)
unnamed: C57.1, D112.1 (K), D113.2 (A)
unnamed: C59.1, D114.1 (K), D115.2 (A)
unnamed: C61.1, D116.1 (K), D117.2 (A)
unnamed: C63.1, D118.1 (K), D119.2 (A)
unnamed: D120.2 (A), D122.2 (A), D124.2 (A), D126.2 (A), D128.2 (A), D130.2 (A), D132.2 (A), D134.2 (A), K8.22
unnamed: C50.1, D120.1 (K), D121.2 (A)
unnamed: D121.1 (K), D123.1 (K), D125.1 (K), D127.1 (K), D129.1 (K), D131.1 (K), D133.1 (K), D135.1 (K), K8.24
unnamed: C52.1, D122.1 (K), D123.2 (A)
unnamed: C54.1, D124.1 (K), D125.2 (A)
unnamed: C56.1, D126.1 (K), D127.2 (A)
unnamed: C58.1, D128.1 (K), D129.2 (A)
unnamed: C60.1, D130.1 (K), D131.2 (A)
unnamed: C62.1, D132.1 (K), D133.2 (A)
unnamed: C64.1, D134.1 (K), D135.2 (A)
unnamed: D136.2 (A), D138.2 (A), D140.2 (A), D142.2 (A), D144.2 (A), D146.2 (A), D148.2 (A), D150.2 (A), K4.12
unnamed: C65.1, D136.1 (K), D137.2 (A)
unnamed: D137.1 (K), D139.1 (K), D141.1 (K), D143.1 (K), D145.1 (K), D147.1 (K), D149.1 (K), D151.1 (K), K4.14
unnamed: C67.1, D138.1 (K), D139.2 (A)
unnamed: C69.1, D140.1 (K), D141.2 (A)
unnamed: C71.1, D142.1 (K), D143.2 (A)
unnamed: C73.1, D144.1 (K), D145.2 (A)
unnamed: C75.1, D146.1 (K), D147.2 (A)
unnamed: C77.1, D148.1 (K), D149.2 (A)
unnamed: C79.1, D150.1 (K), D151.2 (A)
unnamed: D152.2 (A), D154.2 (A), D156.2 (A), D158.2 (A), D160.2 (A), D162.2 (A), D164.2 (A), D166.2 (A), K4.22
unnamed: C66.1, D152.1 (K), D153.2 (A)
unnamed: D153.1 (K), D155.1 (K), D157.1 (K), D159.1 (K), D161.1 (K), D163.1 (K), D165.1 (K), D167.1 (K), K4.24
unnamed: C68.1, D154.1 (K), D155.2 (A)
unnamed: C70.1, D156.1 (K), D157.2 (A)
unnamed: C72.1, D158.1 (K), D159.2 (A)
unnamed: C74.1, D160.1 (K), D161.2 (A)
unnamed: C76.1, D162.1 (K), D163.2 (A)
unnamed: C78.1, D164.1 (K), D165.2 (A)
unnamed: C80.1, D166.1 (K), D167.2 (A)
unnamed: D168.2 (A), D170.2 (A), D172.2 (A), D174.2 (A), D176.2 (A), D178.2 (A), D180.2 (A), D182.2 (A), K3.12
unnamed: C81.1, D168.1 (K), D169.2 (A)
unnamed: D169.1 (K), D171.1 (K), D173.1 (K), D175.1 (K), D177.1 (K), D179.1 (K), D181.1 (K), D183.1 (K), K3.14
unnamed: C83.1, D170.1 (K), D171.2 (A)
unnamed: C85.1, D172.1 (K), D173.2 (A)
unnamed: C87.1, D174.1 (K), D175.2 (A)
unnamed: C89.1, D176.1 (K), D177.2 (A)
unnamed: C91.1, D178.1 (K), D179.2 (A)
unnamed: C93.1, D180.1 (K), D181.2 (A)
unnamed: C95.1, D182.1 (K), D183.2 (A)
unnamed: D184.2 (A), D186.2 (A), D188.2 (A), D190.2 (A), D192.2 (A), D194.2 (A), D196.2 (A), D198.2 (A), K3.22
unnamed: C82.1, D184.1 (K), D185.2 (A)
unnamed: D185.1 (K), D187.1 (K), D189.1 (K), D191.1 (K), D193.1 (K), D195.1 (K), D197.1 (K), D199.1 (K), K3.24
unnamed: C84.1, D186.1 (K), D187.2 (A)
unnamed: C86.1, D188.1 (K), D189.2 (A)
unnamed: C88.1, D190.1 (K), D191.2 (A)
unnamed: C90.1, D192.1 (K), D193.2 (A)
unnamed: C92.1, D194.1 (K), D195.2 (A)
unnamed: C94.1, D196.1 (K), D197.2 (A)
unnamed: C96.1, D198.1 (K), D199.2 (A)
unnamed: D200.2 (A), D202.2 (A), D204.2 (A), D206.2 (A), D208.2 (A), D210.2 (A), D212.2 (A), D214.2 (A), K2.12
unnamed: C97.1, D200.1 (K), D201.2 (A)
unnamed: D201.1 (K), D203.1 (K), D205.1 (K), D207.1 (K), D209.1 (K), D211.1 (K), D213.1 (K), D215.1 (K), K2.14
unnamed: C99.1, D202.1 (K), D203.2 (A)
unnamed: C101.1, D204.1 (K), D205.2 (A)
unnamed: C103.1, D206.1 (K), D207.2 (A)
unnamed: C105.1, D208.1 (K), D209.2 (A)
unnamed: C107.1, D210.1 (K), D211.2 (A)
unnamed: C109.1, D212.1 (K), D213.2 (A)
unnamed: C111.1, D214.1 (K), D215.2 (A)
unnamed: D216.2 (A), D218.2 (A), D220.2 (A), D222.2 (A), D224.2 (A), D226.2 (A), D228.2 (A), D230.2 (A), K2.22
unnamed: C98.1, D216.1 (K), D217.2 (A)
unnamed: D217.1 (K), D219.1 (K), D221.1 (K), D223.1 (K), D225.1 (K), D227.1 (K), D229.1 (K), D231.1 (K), K2.24
unnamed: C100.1, D218.1 (K), D219.2 (A)
unnamed: C102.1, D220.1 (K), D221.2 (A)
unnamed: C104.1, D222.1 (K), D223.2 (A)
unnamed: C106.1, D224.1 (K), D225.2 (A)
unnamed: C108.1, D226.1 (K), D227.2 (A)
unnamed: C110.1, D228.1 (K), D229.2 (A)
unnamed: C112.1, D230.1 (K), D231.2 (A)
unnamed: D232.2 (A), D234.2 (A), D236.2 (A), D238.2 (A), D240.2 (A), D242.2 (A), D244.2 (A), D246.2 (A), K1.12
unnamed: C113.1, D232.1 (K), D233.2 (A)
unnamed: D233.1 (K), D235.1 (K), D237.1 (K), D239.1 (K), D241.1 (K), D243.1 (K), D245.1 (K), D247.1 (K), K1.14
unnamed: C114.1, D234.1 (K), D235.2 (A)
unnamed: C115.1, D236.1 (K), D237.2 (A)
unnamed: C116.1, D238.1 (K), D239.2 (A)
unnamed: C117.1, D240.1 (K), D241.2 (A)
unnamed: C118.1, D242.1 (K), D243.2 (A)
unnamed: C119.1, D244.1 (K), D245.2 (A)
unnamed: C120.1, D246.1 (K), D247.2 (A)
unnamed: C1.2, C9.2, C17.2, C25.2, C33.2, C34.2, C49.2, C50.2, C65.2, C66.2, C81.2, C82.2, C97.2, C98.2, C113.2, D252.2 (A), K9.11
unnamed: C2.2, C10.2, C18.2, C26.2, C35.2, C36.2, C51.2, C52.2, C67.2, C68.2, C83.2, C84.2, C99.2, C100.2, C114.2, D253.2 (A), K9.21
unnamed: C4.2, C12.2, C20.2, C28.2, C39.2, C40.2, C55.2, C56.2, C71.2, C72.2, C87.2, C88.2, C103.2, C104.2, C116.2, D254.2 (A), K10.21
unnamed: C3.2, C11.2, C19.2, C27.2, C37.2, C38.2, C53.2, C54.2, C69.2, C70.2, C85.2, C86.2, C101.2, C102.2, C115.2, D255.2 (A), K10.11
unnamed: C8.2, C16.2, C24.2, C32.2, C47.2, C48.2, C63.2, C64.2, C79.2, C80.2, C95.2, C96.2, C111.2, C112.2, C120.2, D256.2 (A), K12.21
unnamed: C7.2, C15.2, C23.2, C31.2, C45.2, C46.2, C61.2, C62.2, C77.2, C78.2, C93.2, C94.2, C109.2, C110.2, C119.2, D257.2 (A), K12.11
unnamed: C6.2, C14.2, C22.2, C30.2, C43.2, C44.2, C59.2, C60.2, C75.2, C76.2, C91.2, C92.2, C107.2, C108.2, C118.2, D258.2 (A), K11.21
unnamed: C5.2, C13.2, C21.2, C29.2, C41.2, C42.2, C57.2, C58.2, C73.2, C74.2, C89.2, C90.2, C105.2, C106.2, C117.2, D259.2 (A), K11.11
unnamed: J61.3, J61.4
RESET: J51.15
RSTART: J51.16
SIgn: J51.2
Zero: J51.1


Board: 2 copper layers, 253.4 x 291.8 mm, 397 parts (0 on the bottom side), 185 nets.

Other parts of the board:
J12: Conn_02x10_Odd_Even; PinSocket_2x10_P2.54mm_Vertical
J50, J88: Conn_02x20_Counter_Clockwise; PinSocket_2x20_P2.54mm_Vertical
J73: Conn_02x02_Counter_Clockwise; PinSocket_2x02_P2.54mm_Vertical

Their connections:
+5V: J73.3, J73.4
A1: J50.1; also elsewhere on the board
A2: J50.2; also elsewhere on the board
A3: J50.3; also elsewhere on the board
A4: J50.4; also elsewhere on the board
A5: J50.5; also elsewhere on the board
A6: J50.6; also elsewhere on the board
A7: J50.7; also elsewhere on the board
A8: J50.8; also elsewhere on the board
A9: J50.9; also elsewhere on the board
A10: J50.10; also elsewhere on the board
A11: J50.11; also elsewhere on the board
A12: J50.12; also elsewhere on the board
A13: J50.13; also elsewhere on the board
A14: J50.14; also elsewhere on the board
A15: J50.15; also elsewhere on the board
D1: J50.16; also elsewhere on the board
D2: J50.17; also elsewhere on the board
D3: J50.18; also elsewhere on the board
D4: J50.19; also elsewhere on the board
D5: J50.20; also elsewhere on the board
D6: J50.40; also elsewhere on the board
D7: J50.39; also elsewhere on the board
D8: J50.38; also elsewhere on the board
GND: J73.1, J73.2; also elsewhere on the board

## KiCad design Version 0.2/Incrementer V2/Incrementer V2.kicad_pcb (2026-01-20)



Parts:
D11, D12, D18, D19, D20, D21, D26, D32, D33, D34, D35, D36, D42, D44, D45, D46, D47, D51, D56, D59, D60, D61, D62, D66, D72, D73, D74, D75, D76, D82, D86, D87, D88, D89, D95, D96, D97, D98: 1N914; D_DO-35_SOD27_P7.62mm_Horizontal
D103, D104, D105, D106, D107, D108, D109, D110, D111, D112, D113, D114, D115, D116, D117: LED; LED_D5.0mm ohne SilkS
J1: Conn_02x02_Counter_Clockwise; PinSocket_2x02_P2.54mm_Horizontal
J2, J3: Conn_02x20_Counter_Clockwise; PinSocket_2x20_P2.54mm_Horizontal
J4, J5: Conn_01x16; PinHeader_1x16_P2.54mm_Vertical
K7, K8, K12, K13, K14, K15, K20, K25, K26, K27, K28, K29, K34, K35, K36, K37, K38, K42, K46, K49, K50, K51, K52, K55, K60, K61, K62, K63, K64, K69, K72, K73, K74, K75, K80, K81, K82, K83: HK19F-DCxxV-SHC; Relay_DPDT_Finder_30.22 ohne SilkS
R18, R19, R20, R21, R22, R23, R24, R25, R26, R27, R28, R29, R30, R31, R32: R; R_Axial_DIN0204_L3.6mm_D1.6mm_P7.62mm_Horizontal

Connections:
+5V: J1.3, J1.4, J5.16, K7.22, K12.22, K14.22, K26.22, K28.22, K35.22, K37.22, K49.22, K51.22, K61.22, K63.22, K72.22, K74.22, K80.14, K80.22, K80.24, K82.22
A1: J2.1, J5.1, K20.11
A2: J2.2, J5.2, K20.21
A3: J2.3, J5.3, K25.11
A4: J2.4, J5.4, K25.21
A5: J2.5, J5.5, K34.11
A6: J2.6, J5.6, K34.21
A7: J2.7, J5.7, K42.11
A8: J2.8, J5.8, K42.21
A9: J2.9, J5.9, K46.11
A10: J2.10, J5.10, K46.21
A11: J2.11, J5.11, K55.11
A12: J2.12, J5.12, K55.21
A13: J2.13, J5.13, K60.11
A14: J2.14, J5.14, K60.21
A15: J2.15, J5.15, K69.11
Carry Out8: K8.11, K82.12, K83.14
D1: J2.16
D2: J2.17
D3: J2.18
D4: J2.19
D5: J2.20
D6: J2.40
D7: J2.39
D8: J2.38
GND: D11.2 (A), D12.2 (A), D18.2 (A), D19.2 (A), D20.2 (A), D21.2 (A), D26.2 (A), D32.2 (A), D33.2 (A), D34.2 (A), D35.2 (A), D36.2 (A), D42.2 (A), D44.2 (A), D45.2 (A), D46.2 (A), D47.2 (A), D51.2 (A), D56.2 (A), D59.2 (A), D60.2 (A), D61.2 (A), D62.2 (A), D66.2 (A), D72.2 (A), D73.2 (A), D74.2 (A), D75.2 (A), D76.2 (A), D82.2 (A), D86.2 (A), D87.2 (A), D88.2 (A), D89.2 (A), D95.2 (A), D96.2 (A), D97.2 (A), D98.2 (A), D103.1 (K), D104.1 (K), D105.1 (K), D106.1 (K), D107.1 (K), D108.1 (K), D109.1 (K), D110.1 (K), D111.1 (K), D112.1 (K), D113.1 (K), D114.1 (K), D115.1 (K), D116.1 (K), D117.1 (K), J1.1, J1.2, J4.1, K7.A1, K8.A1, K12.A1, K13.A1, K14.A1, K15.A1, K20.A1, K25.A1, K26.A1, K27.A1, K28.A1, K29.A1, K34.A1, K35.A1, K36.A1, K37.A1, K38.A1, K42.A1, K46.A1, K49.A1, K50.A1, K51.A1, K52.A1, K55.A1, K60.A1, K61.A1, K62.A1, K63.A1, K64.A1, K69.A1, K72.A1, K73.A1, K74.A1, K75.A1, K80.12, K80.A1, K81.14, K81.A1, K82.A1, K83.A1
In1: D95.1 (K), D96.1 (K), K20.12, K80.A2, K81.A2
In2: D86.1 (K), D87.1 (K), K20.22, K72.A2, K73.A2
In3: D73.1 (K), D74.1 (K), K25.12, K61.A2, K62.A2
In4: D59.1 (K), D60.1 (K), K25.22, K49.A2, K50.A2
In5: D44.1 (K), D45.1 (K), K34.12, K35.A2, K36.A2
In6: D33.1 (K), D34.1 (K), K26.A2, K27.A2, K34.22
In7: D18.1 (K), D19.1 (K), K12.A2, K13.A2, K42.12
In8: D11.1 (K), D12.1 (K), K7.A2, K8.A2, K42.22
In9: D97.1 (K), D98.1 (K), K46.12, K82.A2, K83.A2
In10: D88.1 (K), D89.1 (K), K46.22, K74.A2, K75.A2
In11: D75.1 (K), D76.1 (K), K55.12, K63.A2, K64.A2
In12: D61.1 (K), D62.1 (K), K51.A2, K52.A2, K55.22
In13: D46.1 (K), D47.1 (K), K37.A2, K38.A2, K60.12
In14: D35.1 (K), D36.1 (K), K28.A2, K29.A2, K60.22
In15: D20.1 (K), D21.1 (K), K14.A2, K15.A2, K69.12
LInc: J3.22
LInst: J3.18
LJ1: J3.15
LJ2: J3.16
LJ: J3.17
LM: J3.11
LM1: J3.9
LM2: J3.10
LMem: J3.25
LMem1: J3.23
LMem2: J3.24
LPC: J3.21
LX: J3.12
LXY: J3.14
LY: J3.13
unnamed: D103.2 (A), R18.1
unnamed: D104.2 (A), R19.1
unnamed: D105.2 (A), R20.1
unnamed: D106.2 (A), R21.1
unnamed: D107.2 (A), R22.1
unnamed: D108.2 (A), R23.1
unnamed: D109.2 (A), R24.1
unnamed: D110.2 (A), R25.1
unnamed: D111.2 (A), R26.1
unnamed: D112.2 (A), R27.1
unnamed: D113.2 (A), R28.1
unnamed: D114.2 (A), R29.1
unnamed: D115.2 (A), R30.1
unnamed: D116.2 (A), R31.1
unnamed: D117.2 (A), R32.1
unnamed: K12.12, K13.14, K27.11
unnamed: K12.14, K12.24, K26.21
unnamed: K7.14, K7.24, K12.21
unnamed: K7.12, K8.14, K13.11
unnamed: K14.12, K15.14, K29.11
unnamed: K14.14, K14.24, K28.21
unnamed: K26.12, K27.14, K36.11
unnamed: K26.14, K26.24, K35.21
unnamed: K28.12, K29.14, K38.11
unnamed: K28.14, K28.24, K37.21
unnamed: K35.12, K36.14, K50.11
unnamed: K35.14, K35.24, K49.21
unnamed: K37.12, K38.14, K52.11
unnamed: K37.14, K37.24, K51.21
unnamed: K49.12, K50.14, K62.11
unnamed: K49.14, K49.24, K61.21
unnamed: K51.12, K52.14, K64.11
unnamed: K51.14, K51.24, K63.21
unnamed: K61.12, K62.14, K73.11
unnamed: K61.14, K61.24, K72.21
unnamed: K63.12, K64.14, K75.11
unnamed: K63.14, K63.24, K74.21
unnamed: K72.12, K73.14, K81.11
unnamed: K72.14, K72.24, K80.21
unnamed: K74.12, K75.14, K83.11
unnamed: K74.14, K74.24, K82.21
RLA: J3.1
RLB: J3.2
RLC: J3.3
RLD: J3.4
RSA: J3.5
RSB: J3.6
RSC: J3.7
RSD: J3.8
Result1: J4.16, K80.11, R18.2
Result2: J4.15, K72.11, R19.2
Result3: J4.14, K61.11, R20.2
Result4: J4.13, K49.11, R21.2
Result5: J4.12, K35.11, R22.2
Result6: J4.11, K26.11, R23.2
Result7: J4.10, K12.11, R24.2
Result8: J4.9, K7.11, R25.2
Result9: J4.8, K82.11, R32.2
Result10: J4.7, K74.11, R31.2
Result11: J4.6, K63.11, R30.2
Result12: J4.5, K51.11, R29.2
Result13: J4.4, K37.11, R28.2
Result14: J4.3, K28.11, R27.2
Result15: J4.2, K14.11, R26.2
SInc: D26.1 (K), D32.1 (K), D42.1 (K), D51.1 (K), D56.1 (K), D66.1 (K), D72.1 (K), D82.1 (K), J3.37, K20.A2, K25.A2, K34.A2, K42.A2, K46.A2, K55.A2, K60.A2, K69.A2
SInst: J3.35
SJ1: J3.32
SJ2: J3.33
SJ: J3.34
SM: J3.28
SM1: J3.26
SM2: J3.27
SMem: J3.40
SMem1: J3.38
SMem2: J3.39
SPC: J3.36
SX: J3.29
SXY: J3.31
SY: J3.30
~Carry Out8: K7.21, K82.14, K82.24


Board: 2 copper layers, 224.4 x 178.6 mm, 111 parts (0 on the bottom side), 91 nets.

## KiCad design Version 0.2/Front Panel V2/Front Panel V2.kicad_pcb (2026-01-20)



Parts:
C1, C2, C3, C4, C5, C6, C7, C8: C; C_Radial_D6.3mm_H5.0mm_P2.50mm
D1, D2, D3, D4, D5, D6, D7, D8, D9, D10, D11, D12, D19, D20, D21, D23, D24, D25, D26, D27, D28, D29, D30, D31, D32, D33, D34, D35, D36, D37, D38, D39, D40, D41, D42, D43, D44, D45, D46, D47, D48, D49, D50, D51, D52, D53, D54, D55, D56, D57, D58, D59, D60, D61, D62, D63, D64, D65, D66: D; D_DO-35_SOD27_P7.62mm_Horizontal
D13, D14, D15, D16, D17, D18, D22: LED; LED_D5.0mm
J1: Conn_02x20_Counter_Clockwise; PinSocket_2x20_P2.54mm_Vertical
J58, J76: Conn_02x20_Counter_Clockwise; PinSocket_2x20_P2.54mm_Horizontal
J59: Conn_02x10_Counter_Clockwise; PinSocket_2x10_P2.54mm_Horizontal
J61: Conn_02x02_Counter_Clockwise; PinSocket_2x02_P2.54mm_Horizontal
K1, K2, K3, K4, K5, K6, K7, K8, K9, K10, K11, K12, K13, K14, K15, K16, K17, K18, K19, K20, K21, K22, K23, K24, K25, K26, K27, K36, K37, K38, K39, K40, K41, K42, K43, K44, K45: HK19F-DCxxV-SHC; Relay_DPDT_Finder_30.22 ohne SilkS
R1, R2, R3, R4, R5, R6, R7: R; R_Axial_DIN0207_L6.3mm_D2.5mm_P7.62mm_Horizontal

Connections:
+5V: J61.3, J61.4, K1.11, K1.21, K2.11, K3.11, K4.11, K5.11, K6.11, K7.21, K8.21, K9.21, K10.21, K11.21, K12.21, K13.11, K13.21, K38.21, K42.21
A1: J58.1, K16.11
A2: J58.2, K16.21
A3: J58.3, K20.11
A4: J58.4, K20.21
A5: J58.5, K17.11
A6: J58.6, K17.21
A7: J58.7, K21.11
A8: J58.8, K21.21
A9: J58.9, K18.11
A10: J58.10, K18.21
A11: J58.11, K22.11
A12: J58.12, K22.21
A13: J58.13, K19.11
A14: J58.14, K19.21
A15: J58.15, K23.11
AUX-ABORT: C8.2, D20.1 (K), D21.1 (K), D60.1 (K), D61.1 (K), D62.1 (K), K14.A2, K15.21, K15.A2
AUX-START: C1.2, D1.1 (K), D7.1 (K), D39.1 (K), K1.A2, K7.A2
Ap-A: K2.14, K37.11, K40.11, K40.21, K44.11, K44.21
Ap-B: K1.14, K37.21, K41.11, K41.21, K45.11, K45.21
Ap-C: K5.14, K39.11, K43.11
Ap-D: K11.14, K39.21, K43.21
B2M: D37.1 (K), J59.8
D1: J58.16, K24.11
D2: J58.17, K24.21
D3: J58.18, K25.11
D4: J58.19, K25.21
D5: J58.20, K26.11
D6: J58.40, K26.21
D7: J58.39, K27.11
D8: J58.38, K27.21
Deposit: D42.2 (A), J1.35
Deposit Next: D43.2 (A), J1.33
Examine: D40.2 (A), J1.36
Examine Next: D41.2 (A), J1.34
GND: C1.1, C2.1, C3.1, C4.1, C5.1, C6.1, C7.1, C8.1, D1.2 (A), D2.2 (A), D3.2 (A), D4.2 (A), D5.2 (A), D6.2 (A), D7.2 (A), D8.2 (A), D9.2 (A), D10.2 (A), D11.2 (A), D12.2 (A), D13.1 (K), D14.1 (K), D15.1 (K), D16.1 (K), D17.1 (K), D18.1 (K), D19.2 (A), D20.2 (A), D21.2 (A), D22.1 (K), D23.2 (A), D24.2 (A), D25.2 (A), D26.2 (A), D27.2 (A), D28.2 (A), D29.2 (A), D30.2 (A), D31.2 (A), D32.2 (A), D33.2 (A), D34.2 (A), D45.2 (A), D46.2 (A), D47.2 (A), D48.2 (A), D49.2 (A), D50.2 (A), D51.2 (A), D52.2 (A), D53.2 (A), D54.2 (A), J61.1, J61.2, K1.A1, K2.A1, K3.A1, K4.A1, K5.A1, K6.A1, K7.A1, K8.A1, K9.A1, K10.A1, K11.A1, K12.A1, K13.A1, K14.A1, K15.A1, K16.A1, K17.A1, K18.A1, K19.A1, K20.A1, K21.A1, K22.A1, K23.A1, K24.A1, K25.A1, K26.A1, K27.A1, K36.A1, K37.A1, K38.A1, K39.A1, K40.A1, K41.A1, K42.A1, K43.A1, K44.A1, K45.A1
LInc: D57.1 (K), J76.22, K45.14
LPC: D56.1 (K), J76.21, K37.24
LoadAdr: D63.2 (A), J1.37
MER: D35.1 (K), J59.9
MEW: J59.10, K41.24
unnamed: C2.2, D2.1 (K), D8.1 (K), K1.24, K2.A2, K8.A2
unnamed: C3.2, D3.1 (K), D9.1 (K), K2.24, K3.A2, K9.A2
unnamed: C4.2, D4.1 (K), D10.1 (K), K4.A2, K10.A2, K14.22
unnamed: C5.2, D5.1 (K), D11.1 (K), K4.24, K5.A2, K11.A2
unnamed: C6.2, D6.1 (K), D12.1 (K), K5.24, K6.A2, K12.A2
unnamed: D13.2 (A), R1.2
unnamed: D14.2 (A), R2.2
unnamed: D15.2 (A), R3.2
unnamed: D16.2 (A), R4.2
unnamed: D17.2 (A), R5.2
unnamed: D18.2 (A), R6.2
unnamed: C7.2, D19.1 (K), K6.24, K13.A2, K14.24
unnamed: D22.2 (A), R7.2
unnamed: D35.2 (A), K44.14
unnamed: D36.2 (A), D37.2 (A), K40.14
unnamed: D38.2 (A), D42.1 (K), D43.1 (K), D47.1 (K), D48.1 (K), D59.2 (A), D60.2 (A), D63.1 (K), D65.1 (K), D66.2 (A), K38.11, K38.A2, K39.A2
unnamed: D38.1 (K), D45.1 (K), D46.1 (K), D62.2 (A), K36.11, K36.A2, K37.A2
unnamed: D39.2 (A), D40.1 (K), D41.1 (K), D44.2 (A), D51.1 (K), D52.1 (K), D61.2 (A), D64.1 (K), D66.1 (K), K42.11, K42.A2, K43.A2
unnamed: D44.1 (K), D64.2 (A)
unnamed: D49.1 (K), D50.1 (K), K38.24, K40.A2, K41.A2
unnamed: D53.1 (K), D54.1 (K), K42.24, K44.A2, K45.A2
unnamed: D55.2 (A), K39.14, K43.14
unnamed: D56.2 (A), K39.24, K43.24
unnamed: D57.2 (A), K41.14, K45.24
unnamed: D58.2 (A), K40.24, K44.24
unnamed: D59.1 (K), D65.2 (A)
unnamed: K1.12, K2.21
unnamed: K2.12, K3.21
unnamed: K4.12, K5.21
unnamed: K5.12, K6.21
unnamed: K7.24, R5.1
unnamed: K8.24, R4.1
unnamed: K9.24, R3.1
unnamed: K10.24, R2.1
unnamed: K4.14, K11.11
unnamed: K11.24, R1.1
unnamed: K12.24, R6.1
unnamed: K13.12, K15.24
unnamed: K13.24, R7.1
unnamed: K3.12, K14.11
unnamed: K4.21, K14.12
unnamed: K3.24, K14.21
SAS: D23.1 (K), D24.1 (K), D25.1 (K), D26.1 (K), D27.1 (K), D28.1 (K), D29.1 (K), D30.1 (K), K16.A2, K17.A2, K18.A2, K19.A2, K20.A2, K21.A2, K22.A2, K23.A2, K37.14
SDS: D31.1 (K), D32.1 (K), D33.1 (K), D34.1 (K), D36.1 (K), K24.A2, K25.A2, K26.A2, K27.A2
SInc: D55.1 (K), J76.37
SPC: D58.1 (K), J76.36
SWA_{1}: J1.1, K16.14
SWA_{2}: J1.2, K16.24
SWA_{3}: J1.3, K20.14
SWA_{4}: J1.4, K20.24
SWA_{5}: J1.5, K17.14
SWA_{6}: J1.6, K17.24
SWA_{7}: J1.7, K21.14
SWA_{8}: J1.8, K21.24
SWA_{9}: J1.9, K18.14
SWA_{10}: J1.10, K18.24
SWA_{11}: J1.11, K22.14
SWA_{12}: J1.12, K22.24
SWA_{13}: J1.13, K19.14
SWA_{14}: J1.14, K19.24
SWA_{15}: J1.15, K23.14
SWD_{1}: J1.16, K24.14
SWD_{2}: J1.17, K24.24
SWD_{3}: J1.18, K25.14
SWD_{4}: J1.19, K25.24
SWD_{5}: J1.20, K26.14
SWD_{6}: J1.40, K26.24
SWD_{7}: J1.39, K27.14
SWD_{8}: J1.38, K27.24
~AUX-RESET: K13.22, K36.14, K38.14, K42.14

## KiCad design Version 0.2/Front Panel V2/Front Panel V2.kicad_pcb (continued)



Board: 2 copper layers, 164.0 x 149.4 mm, 122 parts (7 on the bottom side), 106 nets.

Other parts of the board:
J60: Conn_02x10_Odd_Even; PinSocket_2x10_P2.54mm_Horizontal

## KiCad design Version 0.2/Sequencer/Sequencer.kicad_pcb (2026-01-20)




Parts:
D1, D2, D3, D4, D5, D6, D7, D8, D9, D10, D11, D12, D13, D14, D15, D16, D17, D18, D19, D20, D21, D22, D23, D24, D25, D26, D27, D28, D29, D30, D31, D32, D33, D34, D35, D36, D37, D38, D39, D40, D41, D42, D43, D44, D45, D46, D47, D48, D49, D50, D51, D52, D53, D54, D55, D56, D57, D58: 1N914; D_DO-35_SOD27_P7.62mm_Horizontal
D59, D60, D61, D62, D63, D64, D65, D66, D67, D68, D69, D70, D71, D72, D73, D74, D75, D76, D77, D78, D79, D80, D111: LED; LED_D5.0mm ohne SilkS
J1: Conn_02x25_Counter_Clockwise; PinSocket_2x25_P2.54mm_Horizontal
J4: Conn_02x17_Counter_Clockwise; PinSocket_2x17_P2.54mm_Horizontal
J5: Conn_02x10_Counter_Clockwise; PinSocket_2x10_P2.54mm_Horizontal
J61: Conn_02x02_Counter_Clockwise; PinSocket_2x02_P2.54mm_Horizontal
K1, K2, K3, K4, K5, K6, K7, K8, K9, K10, K11, K12, K13, K14, K15, K16, K17, K18, K19, K20, K21, K22, K23, K24, K25, K26, K27, K28, K29, K30, K31, K32, K33, K34, K35, K36, K37, K38, K39, K40, K41, K42, K43, K44, K45, K46, K47, K48, K49, K50, K51, K52, K53, K54, K55, K56, K57, K58: HK19F-DCxxV-SHC; Relay_DPDT_Finder_30.22 ohne SilkS
R1, R2, R3, R4, R5, R6, R7, R8, R9, R10, R11, R12, R13, R14, R15, R16, R17, R18, R19, R20, R21, R22, R26: R; R_Axial_DIN0204_L3.6mm_D1.6mm_P7.62mm_Horizontal

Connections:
+5V: J61.3, J61.4, K1.11, K1.21, K2.11, K2.21, K5.11, K7.11, K9.11, K11.11, K13.11, K15.11, K17.11, K19.11, K28.11, K28.21, K31.11, K31.21, K41.11, K41.21, K43.11, K45.11, K47.11, K49.11, K50.11, K50.21, K52.11, K54.11, K56.11, K58.11
-RESET: K5.12, K21.11, K25.11, K34.11, K38.11, K55.11
-S1: K3.24, K7.12, K23.11, K27.11, K29.24, K30.24, K32.24, K36.11, K40.11, K57.11
ADD: J4.14
AND: J4.16
AT08: D3.1 (K), J4.10, K3.21, K3.A2
AT08zi: K3.11, K18.24, K19.24
AT08zo: D20.1 (K), D21.1 (K), K3.12, K20.14, K20.A2, K21.A2
AT10: D29.1 (K), J4.11, K29.21, K29.A2
AT10zi: D22.1 (K), D23.1 (K), K20.24, K21.24, K22.A2, K23.A2, K29.11
AT10zo: K22.14, K29.12
AT12: D30.1 (K), J4.12, K30.21, K30.A2
AT12zi: K26.24, K27.24, K30.11
AT12zo: D33.1 (K), D34.1 (K), K30.12, K33.14, K33.A2, K34.A2
AT14: D32.1 (K), J4.13, K32.21, K32.A2
AT14zi: D35.1 (K), D36.1 (K), K32.11, K33.24, K34.24, K35.A2, K36.A2
AT14zo: K32.12, K35.14
B2M: J5.8
C1: K1.14, K4.21
C2: K1.12, K6.21
C3: K1.24, K8.21
C4: K1.22, K10.21
C5: K2.14, K12.21
C6: K2.12, K14.21
C7: K2.24, K16.21
C8: K2.22, K18.21
C9: K20.21, K28.14
C10: K22.21, K28.12
C11: K24.21, K28.24
C12: K26.21, K28.22
C13: K31.14, K33.21
C14: K31.12, K35.21
C15: K31.24, K37.21
C16: K31.22, K39.21
C17: K41.14, K42.21
C18: K41.12, K44.21
C19: K41.24, K46.21
C20: K41.22, K48.21
C21: K50.14, K51.21
C22: K50.12, K53.21
C23: K50.24, K55.21
C24: K50.22, K57.21
CLK: D1.1 (K), D2.1 (K), D28.1 (K), D31.1 (K), D41.1 (K), D50.1 (K), J5.20, K1.A2, K2.A2, K28.A2, K31.A2, K41.A2, K50.A2
CLS: J5.19
Carry: J5.3
F0: J5.4
F1: J5.5
F2: J5.6
FRZ: J5.17
GND: D1.2 (A), D2.2 (A), D3.2 (A), D4.2 (A), D5.2 (A), D6.2 (A), D7.2 (A), D8.2 (A), D9.2 (A), D10.2 (A), D11.2 (A), D12.2 (A), D13.2 (A), D14.2 (A), D15.2 (A), D16.2 (A), D17.2 (A), D18.2 (A), D19.2 (A), D20.2 (A), D21.2 (A), D22.2 (A), D23.2 (A), D24.2 (A), D25.2 (A), D26.2 (A), D27.2 (A), D28.2 (A), D29.2 (A), D30.2 (A), D31.2 (A), D32.2 (A), D33.2 (A), D34.2 (A), D35.2 (A), D36.2 (A), D37.2 (A), D38.2 (A), D39.2 (A), D40.2 (A), D41.2 (A), D42.2 (A), D43.2 (A), D44.2 (A), D45.2 (A), D46.2 (A), D47.2 (A), D48.2 (A), D49.2 (A), D50.2 (A), D51.2 (A), D52.2 (A), D53.2 (A), D54.2 (A), D55.2 (A), D56.2 (A), D57.2 (A), D58.2 (A), D59.1 (K), D60.1 (K), D61.1 (K), D62.1 (K), D63.1 (K), D64.1 (K), D65.1 (K), D66.1 (K), D67.1 (K), D68.1 (K), D69.1 (K), D70.1 (K), D71.1 (K), D72.1 (K), D73.1 (K), D74.1 (K), D75.1 (K), D76.1 (K), D77.1 (K), D78.1 (K), D79.1 (K), D80.1 (K), D111.1 (K), J61.1, J61.2, K1.A1, K2.A1, K3.A1, K4.A1, K5.A1, K6.A1, K7.A1, K8.A1, K9.A1, K10.A1, K11.A1, K12.A1, K13.A1, K14.A1, K15.A1, K16.A1, K17.A1, K18.A1, K19.A1, K20.A1, K21.A1, K22.A1, K23.A1, K24.A1, K25.A1, K26.A1, K27.A1, K28.A1, K29.A1, K30.A1, K31.A1, K32.A1, K33.A1, K34.A1, K35.A1, K36.A1, K37.A1, K38.A1, K39.A1, K40.A1, K41.A1, K42.A1, K43.A1, K44.A1, K45.A1, K46.A1, K47.A1, K48.A1, K49.A1, K50.A1, K51.A1, K52.A1, K53.A1, K54.A1, K55.A1, K56.A1, K57.A1, K58.A1
HALT: J5.18
I1: J4.31
I2: J4.30
I3: J4.29
I4: J4.28
I5: J4.27
I6: J4.26
I7: J4.25
I8: J4.24
IALU: J4.4
IGOTO: J4.8
IINC16: J4.7
ILOAD: J4.5
IMOV8: J4.1
IMOV16: J4.2
INC: J4.15
ISETAB: J4.3
ISTORE: J4.6
MEN: J5.7
MER: J5.9
MEW: J5.10
NOT: J4.33
unnamed: D6.1 (K), D7.1 (K), K4.24, K5.24, K6.14, K6.A2, K7.A2
unnamed: D8.1 (K), D9.1 (K), K6.24, K7.24, K8.14, K8.A2, K9.A2
unnamed: D10.1 (K), D11.1 (K), K8.24, K9.24, K10.14, K10.A2, K11.A2
unnamed: D14.1 (K), D15.1 (K), K12.24, K13.24, K14.14, K14.A2, K15.A2
unnamed: D16.1 (K), D17.1 (K), K14.24, K15.24, K16.14, K16.A2, K17.A2
unnamed: D18.1 (K), D19.1 (K), K16.24, K17.24, K18.14, K18.A2, K19.A2
unnamed: D24.1 (K), D25.1 (K), K22.24, K23.24, K24.14, K24.A2, K25.A2
unnamed: D26.1 (K), D27.1 (K), K24.24, K25.24, K26.14, K26.A2, K27.A2
unnamed: D37.1 (K), D38.1 (K), K35.24, K36.24, K37.14, K37.A2, K38.A2
unnamed: D39.1 (K), D40.1 (K), K37.24, K38.24, K39.14, K39.A2, K40.A2
unnamed: D44.1 (K), D45.1 (K), K42.24, K43.24, K44.14, K44.A2, K45.A2
unnamed: D46.1 (K), D47.1 (K), K44.24, K45.24, K46.14, K46.A2, K47.A2
unnamed: D48.1 (K), D49.1 (K), K46.24, K47.24, K48.14, K48.A2, K49.A2
unnamed: D53.1 (K), D54.1 (K), K51.24, K52.24, K53.14, K53.A2, K54.A2
unnamed: D55.1 (K), D56.1 (K), K53.24, K54.24, K55.14, K55.A2, K56.A2
unnamed: D57.1 (K), D58.1 (K), K55.24, K56.24, K57.14, K57.A2, K58.A2
unnamed: D59.2 (A), R1.1
unnamed: D60.2 (A), R2.1
unnamed: D61.2 (A), R3.1
unnamed: D62.2 (A), R4.1
unnamed: D63.2 (A), R5.1
unnamed: D64.2 (A), R6.1
unnamed: D65.2 (A), R7.1
unnamed: D66.2 (A), R8.1
unnamed: D67.2 (A), R9.1
unnamed: D68.2 (A), R10.1
unnamed: D69.2 (A), R11.1
unnamed: D70.2 (A), R12.1
unnamed: D71.2 (A), R13.1
unnamed: D72.2 (A), R14.1
unnamed: D73.2 (A), R15.1
unnamed: D74.2 (A), R16.1
unnamed: D75.2 (A), R17.1
unnamed: D76.2 (A), R18.1
unnamed: D77.2 (A), R19.1
unnamed: D78.2 (A), R20.1
unnamed: D79.2 (A), R21.1
unnamed: D80.2 (A), R22.1
unnamed: D111.2 (A), R26.1
unnamed: K4.11, K9.12
unnamed: K6.11, K11.12
unnamed: K12.11, K17.12
unnamed: K14.11, K19.12
unnamed: K20.11, K25.12
unnamed: K22.11, K27.12
unnamed: K33.11, K38.12
unnamed: K35.11, K40.12
unnamed: K42.11, K47.12
unnamed: K44.11, K49.12
unnamed: K51.11, K56.12
unnamed: K53.11, K58.12
OR: J4.17
RESET: D4.1 (K), D5.1 (K), J5.15, K3.14, K4.14, K4.A2, K5.A2, K29.14, K30.14, K32.14, K57.24
RSET: J4.9
RSTART: J5.16
S0': J1.1, K5.14
S1: J1.50, K7.14, R26.2
S1': J1.2, K5.21
S2: J1.49, K9.14, R1.2
S2': J1.3, K7.21
S3: J1.48, K11.14, R2.2
S3': J1.4, K9.21
S4: J1.47, K13.14, R3.2
S4': J1.5, K11.21
S5: J1.46, K15.14, R4.2
S5': J1.6, K13.21
S6: J1.45, K17.14, R5.2
S6': J1.7, K15.21
S7: J1.44, K19.14, R6.2
S7': J1.8, K17.21
S8: J1.43, K21.14, R7.2
S8': J1.9, K19.21
S9: J1.42, K23.14, R8.2
S9': J1.10, K21.21
S10: J1.41, K25.14, R9.2
S10': J1.11, K23.21
S11: J1.40, K27.14, R10.2
S11': J1.12, K25.21
S12: J1.39, K34.14, R11.2
S12': J1.13, K27.21
S13: J1.38, K36.14, R12.2
S13': J1.14, K34.21
S14: J1.37, K38.14, R13.2
S14': J1.15, K36.21
S15: J1.36, K40.14, R14.2
S15': J1.16, K38.21
S16: J1.35, K43.14, R15.2
S16': J1.17, K40.21
S17: J1.34, K45.14, R16.2
S17': J1.18, K43.21
S18: J1.33, K47.14, R17.2
S18': J1.19, K45.21
S19: J1.32, K49.14, R18.2
S19': J1.20, K47.21
S20: J1.31, K52.14, R19.2
S20': J1.21, K49.21
S21: J1.30, K54.14, R20.2
S21': J1.22, K52.21
S22: J1.29, K56.14, R21.2
S22': J1.23, K54.21
S23: J1.28, K58.14, R22.2
S23': J1.24, K56.21
SHL: J4.34
SIgn: J5.2
XOR: J4.32
Xa: K8.11, K13.12
Xb: K16.11, K21.12
Xc: K24.11, K34.12
Xd: K37.11, K43.12
Xe: K46.11, K52.12
Ya: K10.11, K15.12
Yb: K18.11, K23.12
Yc: K26.11, K36.12
Yd: K39.11, K45.12
Ye: K48.11, K54.12
Za: D12.1 (K), D13.1 (K), K10.24, K11.24, K12.14, K12.A2, K13.A2
Zd: D42.1 (K), D43.1 (K), K39.24, K40.24, K42.14, K42.A2, K43.A2
Ze: D51.1 (K), D52.1 (K), K48.24, K49.24, K51.14, K51.A2, K52.A2
Zero: J5.1
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

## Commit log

2026-01-20 Second Version, overall improvements.
    Added Tape Loader and Front Panel Function Board aswell
    [ALU V2 v2 - Logik.kicad_pcb, ALU V2 v2 - Logik.kicad_sch, ALU V2.kicad_pcb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]
2026-06-26 Mostly complete version of the RC-1 made in ttl
    Version of the Computer made out of TTL Chips. Should be compatible with the relay version, although not tested yet.
2026-10-01 Newer revision of the TTL Variant
    The TTL Variant, as a proof of concept, is nearly done! A few things have changed since the last revision, and with every fix becomes abundantly clear that the Relay version will need a lot more work before im completly satisfied with the results.
2026-10-01 Bugs and Issues I currently have with the RC-1
    This is a limited list of Issues Bugs I have discovered that currently still exist in my latest revision. These bugs are nothing that makes the computer unusable, it just needs workarounds that I find particularly annoying. I drifted off the topic in this document, but still relevant nonetheless.
